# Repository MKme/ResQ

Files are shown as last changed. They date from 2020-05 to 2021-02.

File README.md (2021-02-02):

# RESQ Open Source Wifi based Search and Rescue Devices
Moving super secret source to Git for sharing on Hackaday- time to give ths project away  Show it some love with a like on Hackaday IO here: https://hackaday.io/project/172090-resq-search-and-rescue-tools

Buy a DIY kit here: https://store.mkme.org/?product_cat=custom

This open source project uses beacon packet sniffing from any commercially available aircraft/drone or manned aircraft OR by a handheld YAGI antenna unit to locate people on the ground such as lost hikers, 
campers or even poachers on game preserves etc This will work even in areas where their cellphones cannot connect to any cell tower- handy.  The aircraft dtects the AP beacon from their cellular phone, records the GPS coordinates for later ground use and transmits an alert to search teams on the ground
<p align="center">
<br>
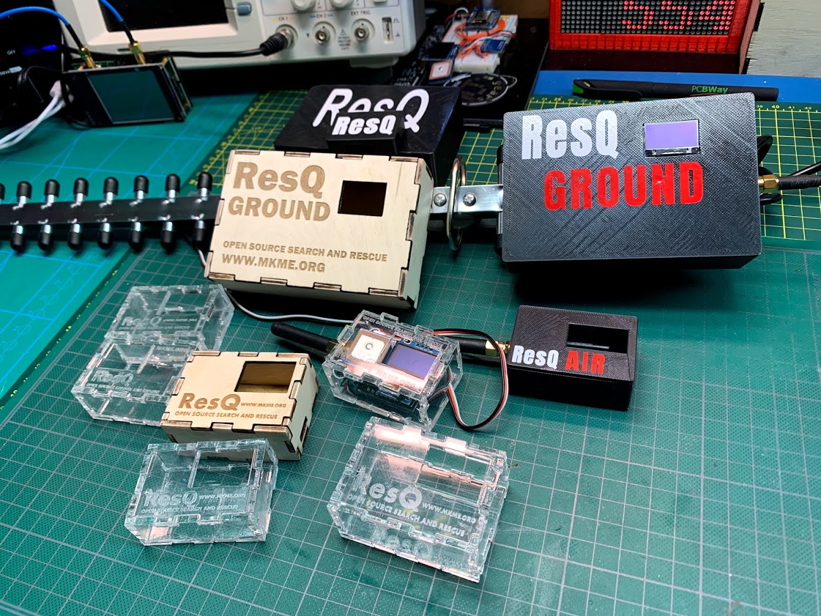
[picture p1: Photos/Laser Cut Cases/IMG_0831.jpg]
 
 <br>

<br>
<br>
🐦 <a href="https://twitter.com/mkmeorg">Twitter</a>
| 📺 <a href="https://www.youtube.com/mkmeorg">YouTube</a>
| 🌍 <a href="http://www.mkme.org">mkme.org</a><br>
Support this project and become a patron on <a href="http://mkme.org/patreon">Eric's Patreon</a>.<br>
Website, Forum and store are at http://mkme.org <br>
Chat with Me: <a href="https://discord.gg/j9S4Fgv">Discord</a></b>
</p>

# Links for more information
Hackaday Project: https://hackaday.io/project/172090-resq-open-source-search-and-rescue-tool

ResQ Tool Forum Thread For Discussion with Eric - http://mkme.org/forum/viewtopic.php?f=28&t=1130

# FULL video tutorials:

### Full playlist (all related videos/tutorials):

https://www.youtube.com/playlist?list=PLxyM2a_cfnzifVreG8aKurH-9nNYl8QLr

# Main Overview:
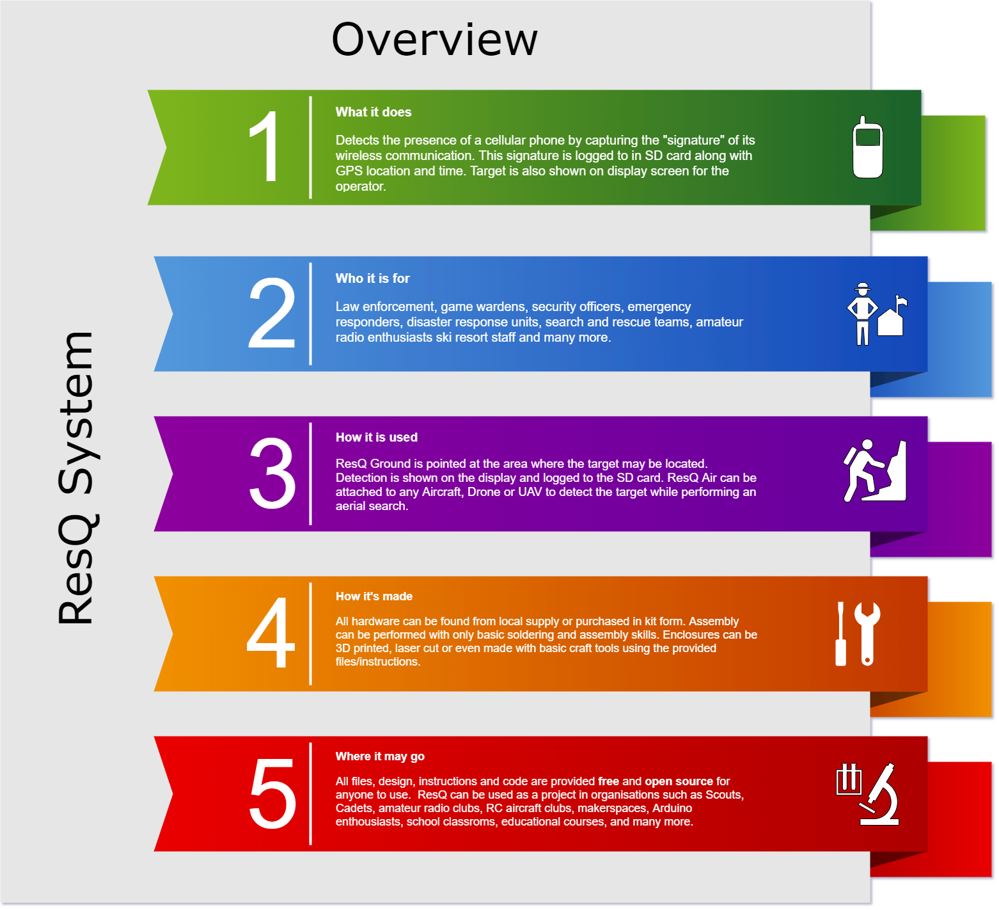
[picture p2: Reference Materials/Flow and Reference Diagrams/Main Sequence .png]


# System Overview 
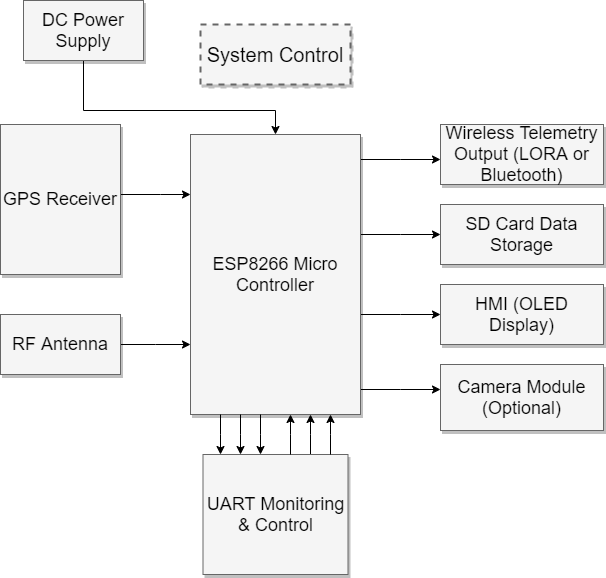
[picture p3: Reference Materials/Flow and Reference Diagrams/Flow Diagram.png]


# Kanban Board- Current Status of ResQ
 
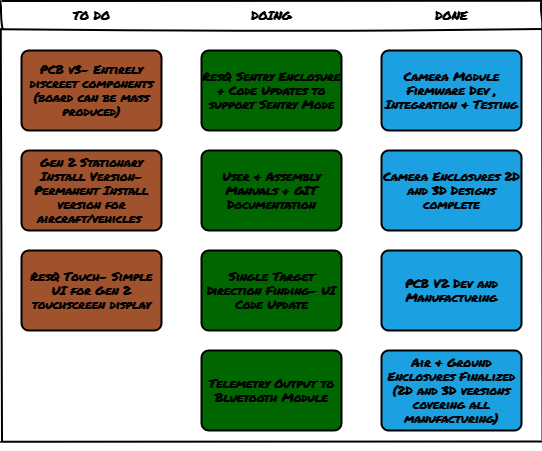
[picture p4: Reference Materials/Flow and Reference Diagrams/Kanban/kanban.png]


#  Bill of Materials 

This list is shortened for brevity - Full BOM in excel doc in BOM folder

| Component | Source  |
| --- |---|
|D1 Mini Pro | https://amzn.to/2ZQArbl
|Custom PCB |  https://store.mkme.org/?product_cat=custom
|D1 Mini With antenna included| https://amzn.to/2ZNQEy1
|SD Card Reader| https://amzn.to/2XPDv6B
|0.96" OLED Display| https://amzn.to/3cCHvvj
|2.4 GHz Yagi Antenna| https://amzn.to/3gwLso9
|BN220 GPS| https://amzn.to/2ZPXUJH
|SMA adapter| https://amzn.to/3ezOpT8
|LORA Modules| https://amzn.to/2zB61ze
|18650 LiOn cells | https://amzn.to/2ZSoMsz

# Wiring 
See schematic and PCB gerber files for detailed view but this is the summary
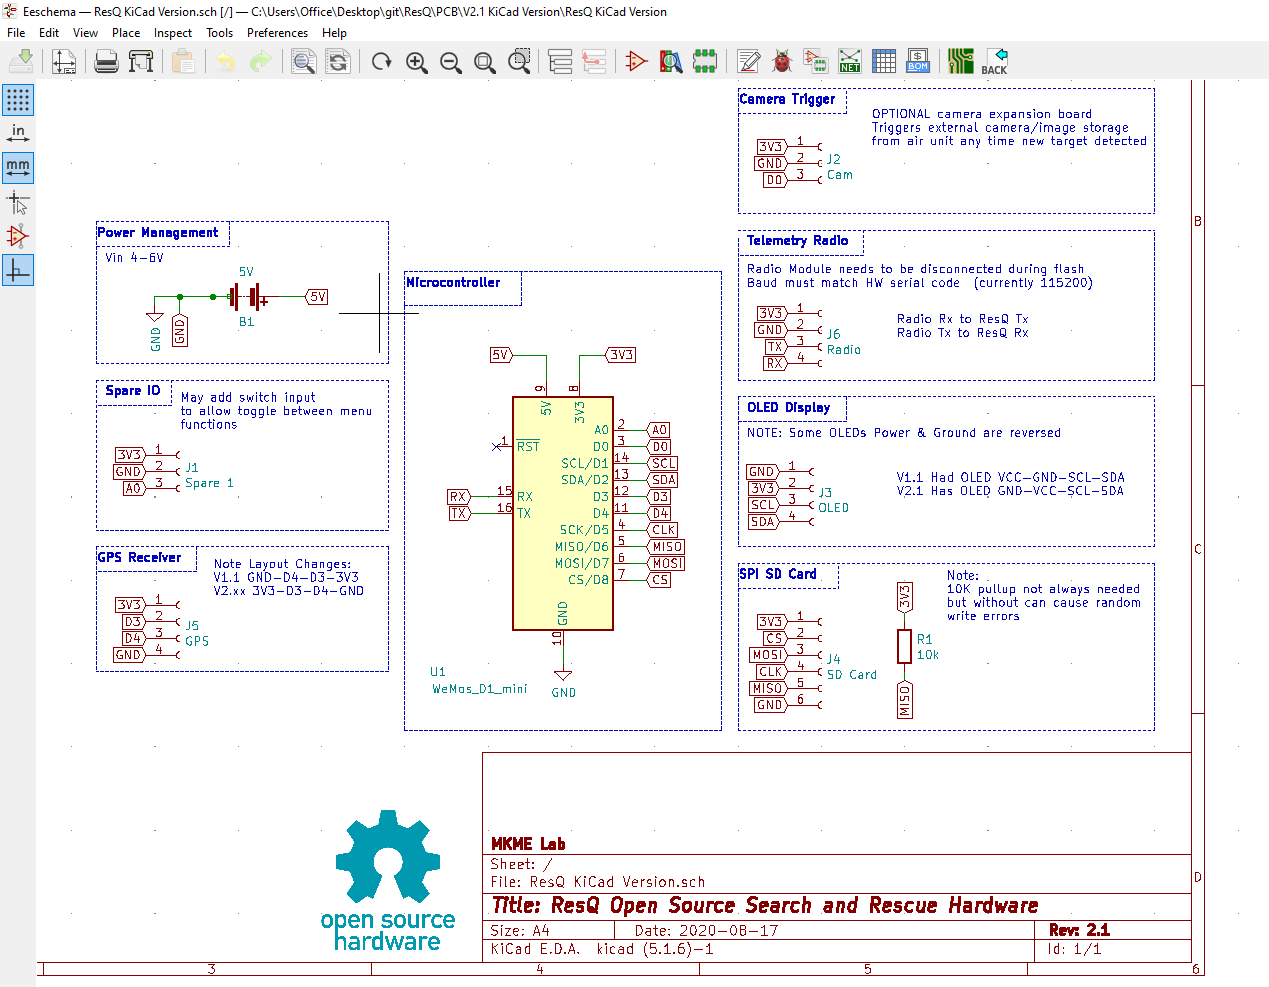
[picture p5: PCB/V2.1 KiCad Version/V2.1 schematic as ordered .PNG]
 

### SPI SD Card to WEMOS D1  Wiring
| Pin On SD Reader | Pin on D1  |
| --- |---|
| SCK  | D5 |
| MISO| D6 |
| MOSI  | D7 |
| CS  | D8  |
|GND | GND |
|VCC  | 3.3V ONLY!  |

### 0.96" OLED to WEMOS D1 
| Pin On OLED | Pin on D1  |
| --- |---|
| SDA  | D2 |
| SCL| D1 |
|GND | GND |
|VCC  | 3.3V or 5V (depends on display)  |

### BN220 GPS Module
| Pin On GPS | Pin on Wemos D1  |
| --- |---|
| TX | 4 (2 in Arduino code) |
| RX | 3 (0 in Arduino code) |
|GND | GND |
|VCC  | 3.3V |

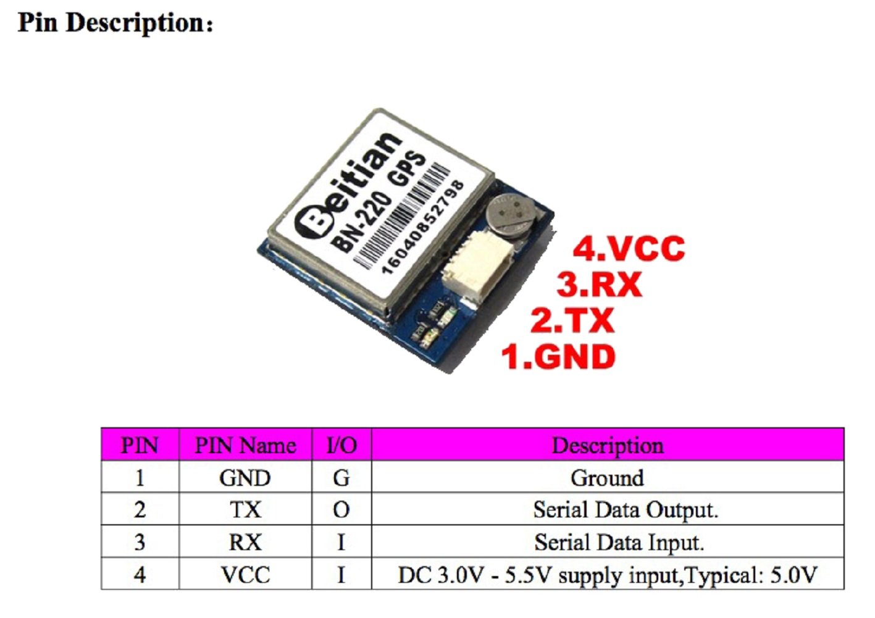
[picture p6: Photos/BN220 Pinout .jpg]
 

# Enclosure/CAD Files Notes
- V1.4 Air unit case is first compatible enclusure for V1.1 PCBs/Gerbers as manufactured/supplied
- All boards and enclusures will follow version 1.XX will be compatible with all 1.XX PCBs and onward to 2.xx etc
- This project is my first made with Fusion 360 
- This was made from the awesome Adafruit Tutorial here (Thanks Noe!) https://www.youtube.com/watch?v=VVmOtM60VWw
- The box is fully parametric in Fusion so you can easily modify it as your needs/expansion or future changes to this project- HANDY!

# PCB Notes
## V1.1 
First to be manufactured (PCBWay)
- OLED is powered by 5V not 3.3V (just note in case yours is not 5V tolerant)
- OLED Wiring startes with VCC on the end then GND- Apparently almost every other OLED in the world outside my shop starts with GND then VCC
- OLED can be wired backwards as above point and burn your fingers....twice.... but still works after.... sigh....

## V2.1 
Project files done in KiCAD
- OLED is now powered 3.3V not 5V
- OLED VCC and Grnd reversed to accomodate the much more common pin layout 
-Pullup resistor added for SPI line
- Spare Signal wires now routed and dont need bodge wires if used
- Serial lines broken out for teletry transmission via LORA radio (or other UART radio module)

# Camera Expansion Module

ResQ Camera expansion module automatically captures images when target is aquired. This uses an ESP32 with camera
module. With the single GPIO I use this as an interrupt driven signal to wake the ESP from deep-sleep then begin capturing images to the SD card

The images can be used to correlate with the satellite imagery or existing aircraft FPV DVR footage.  It may be handy to have standalone images to quikly review any target detected. 

The code and enclosure files are now posted to this repo for all to use. Refer to the assembly manual for details. 

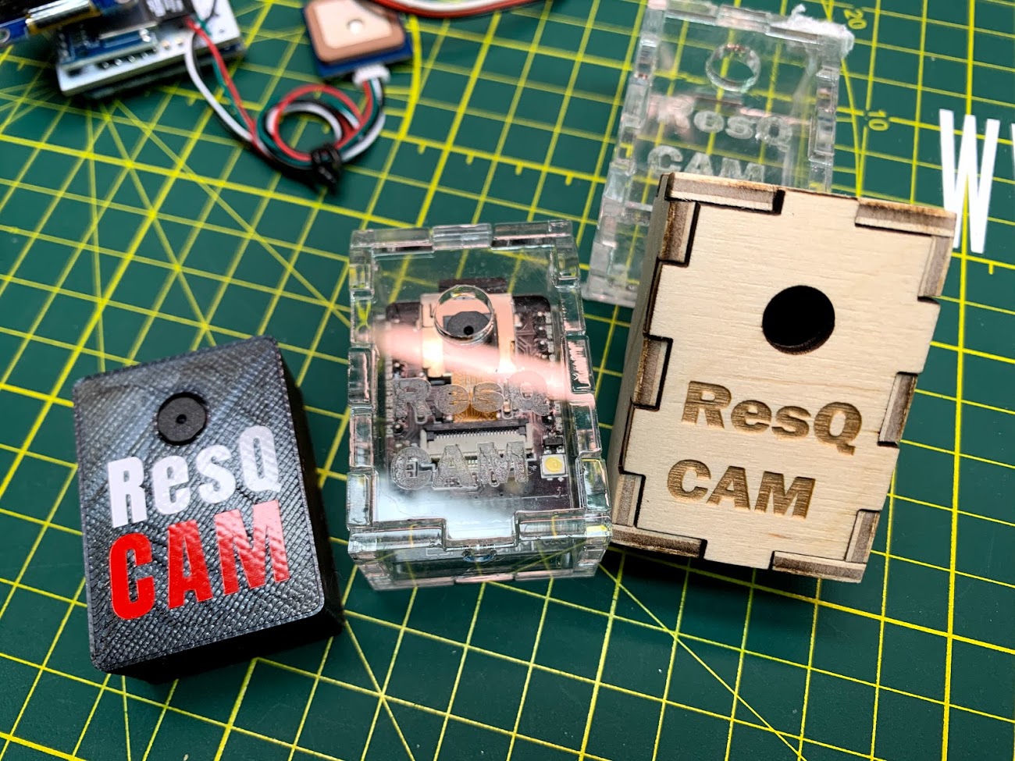
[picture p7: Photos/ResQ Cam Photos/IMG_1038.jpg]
 

# ResQ Sentry

Sentry is a ResQ variant which includes the existing hardware plus the camera module inside a case which then becomes a stationary camera for monitoring human traffic in any area. Any time a new cell phone MAC address is detected- the camera module is triggered and captures still images of the area. 

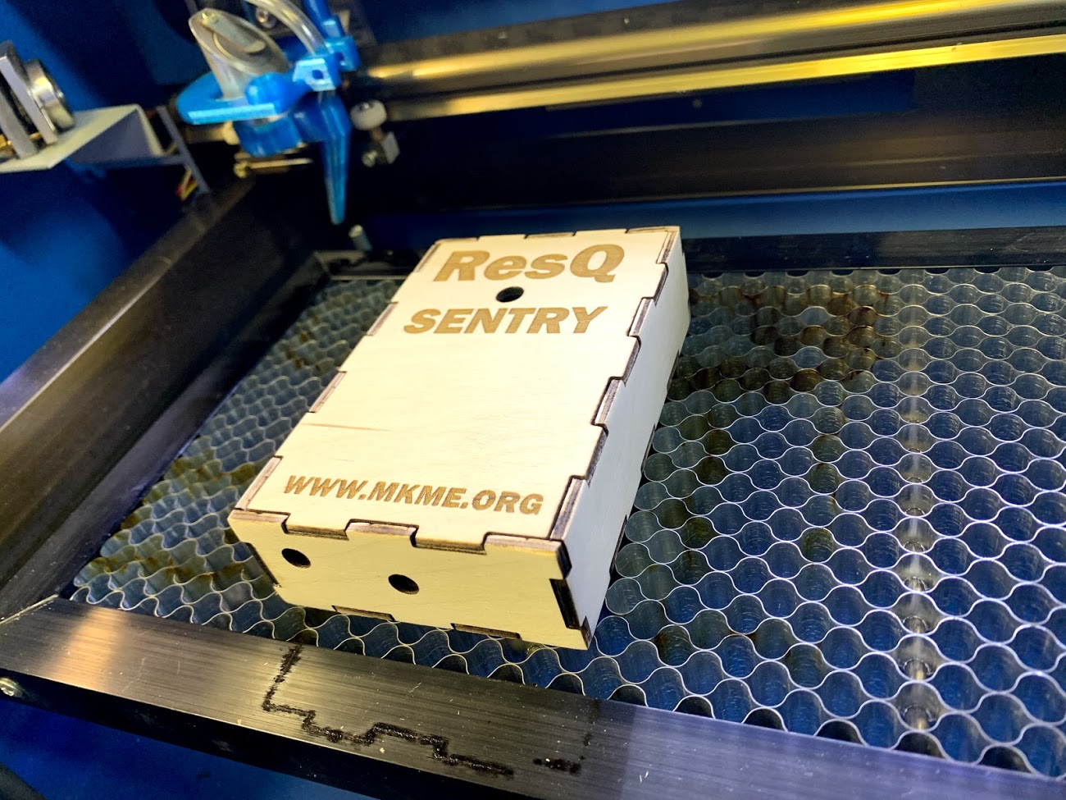
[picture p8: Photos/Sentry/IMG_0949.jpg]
 
 
This can be used in game preserves to catch poachers, private property surveillance, restricted areas, and many more! 

The GPS is still used to allow for accurate date/time stamps without the need for adding a real time clock. Time function will work without clear line of site to any satellites (it works indoors just fine).

2 different enclosures are provided:

- 	3D printable .stl version
-  Laser cut version (.svg files)

1. Install the ResQ hardware along with the camera in to the Sentry enclosure (camera through front hole)

2. Power the Sentry with an appropriate battery supply (5VDC to the ResQ) 

3. Add an appropriate solar charging system if desired (I bought this panel for $21 CAD) https://amzn.to/3hOA5qX

# Reviewing a Search Result Data Recording

All data is stored to the SD card while the unit is powered on. Perform your search then afterward- remove the SD card and download the contents to your PC. The file is datalog.txt 

You can manually review the hits and plot them one by one in Google Maps or your preffered map software or you can do them all at once: 

1. Download the datalog.txt file, 

2. Rename from datalog.txt to datalog.csv

3. Open in excel - Add a row above the data and within that row add the text LAT, LONG and MAC  above the corresponding columns for each (this will tell Google what each column is)

4. Delete all other columns as we wont need those

5. Upload to Google maps as done here https://www.youtube.com/watch?v=SLMzhOoA29M  NOTE: Google seems to limit the plots to 2000 entries so ensure your CSV file only has less than 2000 lines. 

Now You can then see all the MAC addresses plotted on a map- HANDY! 

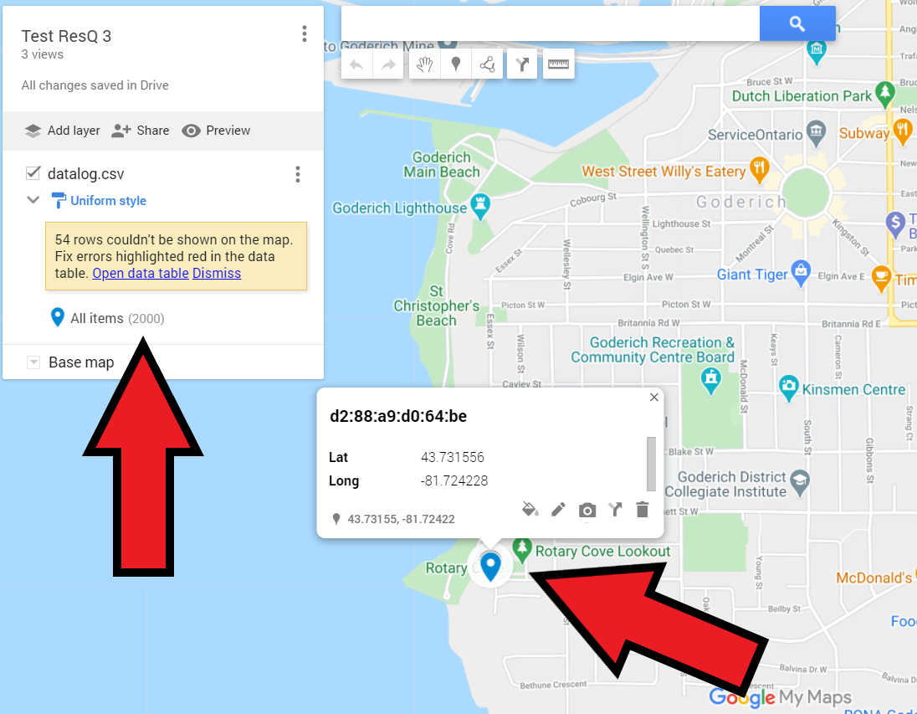
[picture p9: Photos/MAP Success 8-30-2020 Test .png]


# Reference & Press Coverage
Hackaday Article: https://hackaday.com/2020/08/12/resq-hunts-for-lost-hikers-from-the-air/

Hackaday Prize 2020 Finalist status: https://hackaday.io/contest/171491-supplyframe-designlab-2020-hackaday-prize/log/183401-2020-hackaday-prize-finalists

Hackster I.O Article: https://www.hackster.io/news/resq-aims-to-help-find-lost-hikers-by-capturing-wifi-beacon-frames-6608e10e4b22

Adafruit Article: https://blog.adafruit.com/2020/08/17/resq-hunts-for-lost-hikers-from-the-airdrone-droneday/

More videos and information at http://youtube.com/mkmeorg or http://www.mkme.org
Support this project and become a patron on <a href="http://mkme.org/patreon">Eric's Patreon</a>.<br>
Website, Forum and store are at http://mkme.org <br>
Chat with Me: <a href="https://discord.gg/j9S4Fgv">Discord</a></b>

### ResQ Components/build:

D1 mini Pro External Antenna (you need to mod the board for the external to work)  https://youtu.be/hXRcJXMjlyg

SD Card Use: https://youtu.be/y-P627KBLBw
SD Card interface: http://mkme.org/forum/viewtopic.php?f=14&t=1126&p=1430#p1430

### Drone/Aircraft Builds and Tuning:

Nano Talon Build Pt 1 https://youtu.be/BveRkukH6Sg

Nano Talon Build Pt 2 https://youtu.be/9segL9kFlmg

Nano Talon Build Pt 3 https://youtu.be/56KqzPDGRqc

Nano Talon Build Pt 4 https://youtu.be/-qZ3yurwyJo

Adding 3DR telemetry radio to the Nano Talon for autonymous flight control https://youtu.be/XCQz9AeE2qA

Making a DIY 18650 2S1P battery pack for >1hr duration flight missions https://youtu.be/XwAqgR_XsYw

### Attribution

This work is licensed under a Creative Commons Attribution-NonCommercial 4.0 International License.
https://creativecommons.org/licenses/by-nc/4.0/
See notes.h and comments in main code for detailed lineage/license info

Credit M. Ray Burnette for publication as WiFi Sniffer 20161013 (MIT) 
Source https://www.hackster.io/rayburne/esp8266-mini-sniff-f6b93a  
Ray's example helped this whole project by providing a base to work and expand from.  Ray your code caused me to pull my hair out and jump for joy many many nights. You rock. I apologise for the current mess that once resembled some of your code :) 

Credit to Andreas Spiess for inspiring all of us to use ESP8266 boards more in our projects (Andreas=father of all ESP projects) : https://www.youtube.com/channel/UCu7_D0o48KbfhpEohoP7YSQ

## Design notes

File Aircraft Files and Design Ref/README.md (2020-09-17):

# Aircraft Ref

### Welcome to Erics land of ResQ Aircraft Reference Materials
This area is for my aircraft goodies and drone configs.  

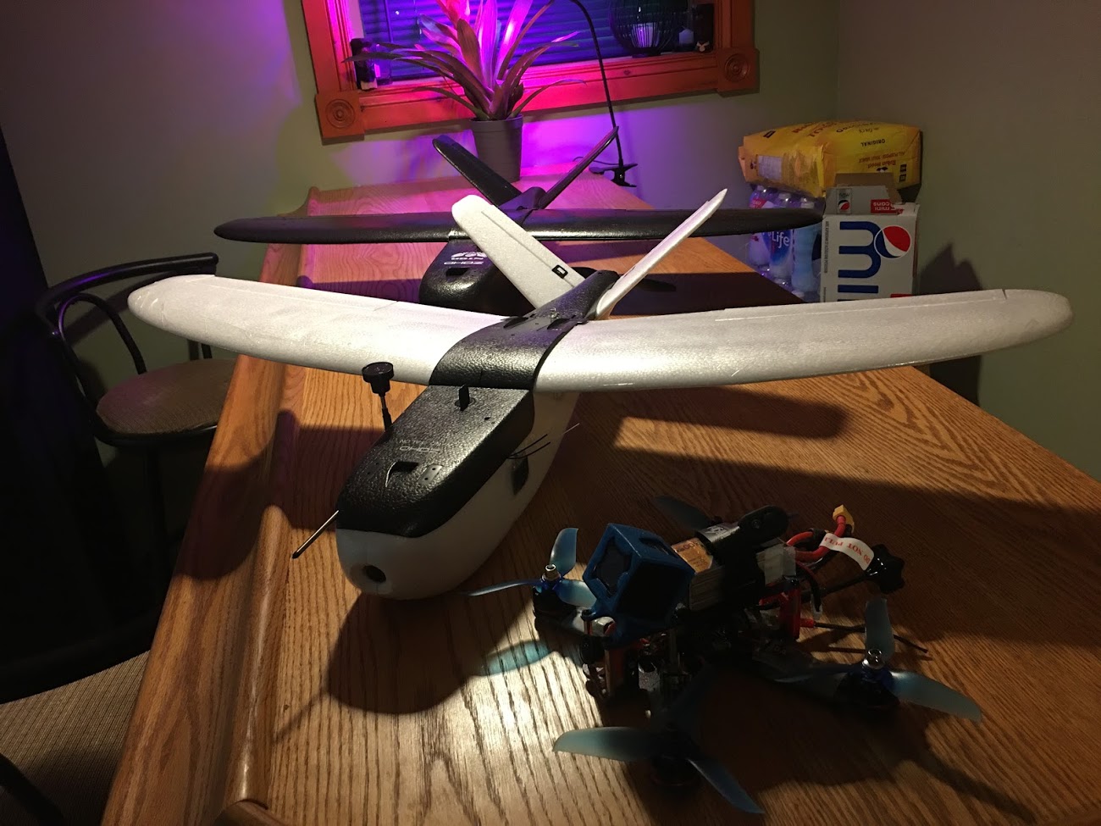
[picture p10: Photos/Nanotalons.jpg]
 

# Aircraft Notes 

4-1-2020:

- iNav fully updated and old settings manually inputted. 433mhz telemetry working for wireless/mission

July 2020:

- inav fully tested- just needs final autotune or pid adjustments

- trim good

- all modes working

- transition to RTH is still rough and too high throttle- would be nice to reduce this but seems to rely on rate or some combination

See my YouTube videos in the ResQ playlist https://www.youtube.com/playlist?list=PLxyM2a_cfnzifVreG8aKurH-9nNYl8QLr

Also see my entire Github repo devoted to my drone configs (ALL OF THEM) here:  https://github.com/MKme/DroneConfigs

See the CAD files folder for my 3D printed parts

In the iNav folder you will find all my iNav config files for the Nano Talon. You should be able to use them directly in your build should you use the same airframe.  

More configs coming Fall 2020 when I build the new heavy-lift quadcopter. 

## TIPS- 

-  I have the aircraft and quacopter parts avaialble on my website here: http://store.mkme.org

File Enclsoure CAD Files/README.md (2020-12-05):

# Enclosures Assembly & Manufacturing Guide

### Welcome to Erics land of enclosures where everyone leaves with a shiny new project case. No matter what tools you have we have a case for you. No money down, no interest for all the days! 

 

Here we have a variety of selections for your ResQ build.  Choose from the standard CAD files and .stls for 3D printing

### or

Try out the new and improved 2D svg files to laser, CNC or even hand cut your own!  No special equipment needed anymore. My goal was to make sure no one would be limited by their access to machinery or equipment- below are options for multiple enclosures depending on what you have access to or even nothing at all!

## 3D Printer Settings

Print in your material of choice. I use PLA:

- 0.3mm Layer height

- 210C extruder

- No Supports

- 15% Infill Rectillinear

You find ALL my i3 printer settings in GIT here:  https://github.com/MKme/I3-Mega-3D-Printer-Settings-Resources

Or All my CR10 settings and profiles in GIT here:  https://github.com/MKme/CR10-3D-Printer-Settings-and-Reference

## Laser Cutter Settings
On my K40 (40 Watt Chinese laser cutter) You can find all my reference and info for the K40 in my Git Repo Here: https://github.com/MKme/Laser-Cutter

Settings Used for these designs: 

### Acrylic

- Raster: 10% power 100mm/second

- Vector Cuts: 60% power 3mm/s 

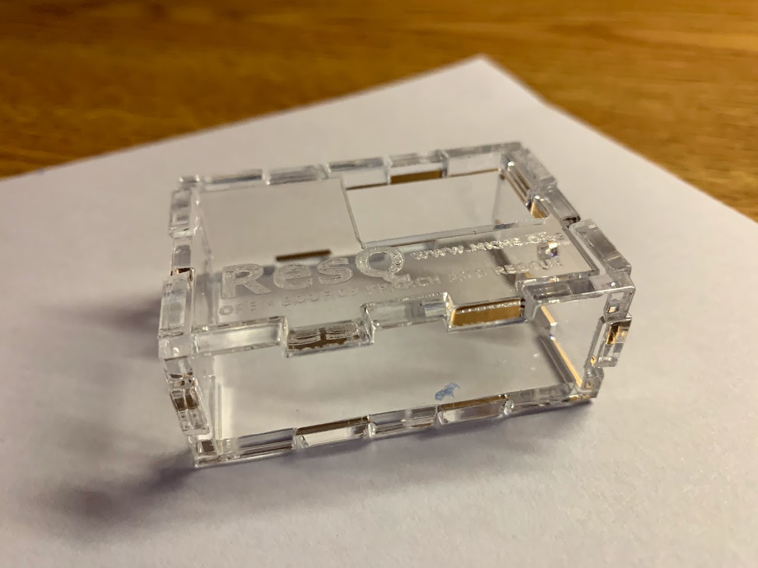
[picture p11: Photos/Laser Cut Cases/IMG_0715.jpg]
 

### 3mm Birch Plywood

- Raster: 11% power 100mm/second

- Vector Cuts: 60% power 3mm/s 

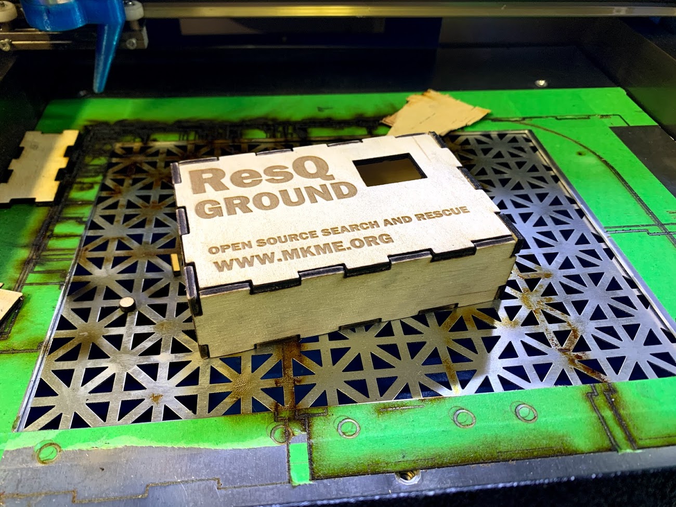
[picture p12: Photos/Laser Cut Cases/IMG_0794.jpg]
 

## CNC
I dont have one yet but if you have tips please let me know so I can add them to the assembly guide and this doc!

*EDIT* I bough a 3018 CNC to test these 2D files and see how they cut compared to the laser. If there is anything I can do to fix them for others to easily make them I will. 

## Hand cutting

Print out the design on paper then trace it on your material of choice and cut it out.  

Just that easy! 

### TIPS- 

- Hand made verision : Use DollarTree foam board then just wrap it in packing tape for a super durable enclosure that costs you a dollar.  

- Modify the Box files yourself- If you want different dimensions simply go to this site: https://en.makercase.com/#/ Enter the dimensions you want and export the .svg for FREE

## Enclosure/CAD Files Notes

V1.4 Air unit case is first compatible enclusure for V1.1 PCBs/Gerbers as manufactured/supplied

All boards and enclusures will follow version 1.XX will be compatible with all 1.XX PCBs and onward to 2.xx etc

This project is my first made with Fusion 360

Fusion 360 models were made from the awesome Adafruit Tutorial here (Thanks Noe!) https://www.youtube.com/watch?v=VVmOtM60VWw

The fusion 360 boxes are fully parametric in Fusion so you can easily modify it as your needs/expansion or future changes to this project- HANDY!

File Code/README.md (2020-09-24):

# Code Guide

### Welcome to Erics land of ResQ Arduino Code
This is where you will find the current code/firmware for the ResQ project 

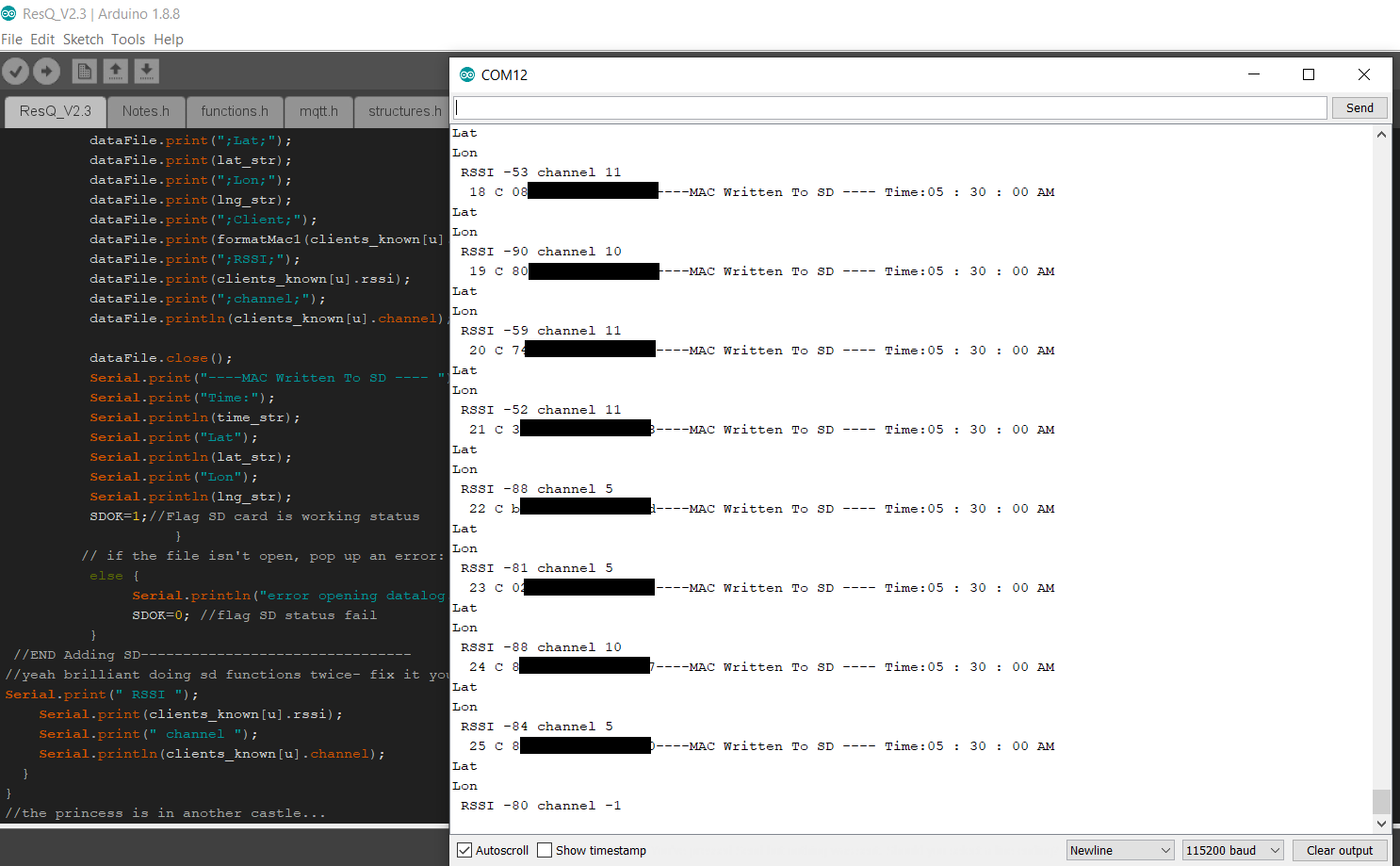
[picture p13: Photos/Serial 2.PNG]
 

# Code Notes

To program the ESP8266 you need to install the Arduino IDE, ESP8266 board support within the IDE and the CH340 USB to Serial driver (if not already installed on your PC)
To do this follow the tutorial here:  

https://www.youtube.com/watch?v=q2k3CzT5qE0&ab_channel=MakersMadLab

NOTE: ResQ kits come with the ESP8266 programmed with the current ResQ firmware at the time of manufacture. 

Install the supporting libraries called out in the sketch (they are also included as backups in the GitHub Repo for you as libraries can be broken by new development.  Needed libraries are: 

•	ArduinoJson

•	TinyGPSPlus-1.0.2/TinyGPSPlus-1.0.2

•	U8g2-2.27.6

•	EspSoftwareSerial-6.8.1.zip

For help installing libraries see this video: 

https://www.youtube.com/watch?v=M6PZOqNHKxM&ab_channel=Brainy-Bits

Flash the most current ResQ firmware (sketch) found on GitHub here: https://github.com/MKme/ResQ/tree/master/Code

## Options 

Sentry Mode can be enabled in setup by changing:

int SENTRYMODE = 0;

to

int SENTRYMODE = 1;

This will turn off the OLED after unit is fully initialized and detects the first target thereby saving battery power for solar/battery installs

## TIPS- 

-  I have the PCBs avaialble on my website here: http://store.mkme.org/product-category/custom/
-  Backups of the working libraries are found in this directory

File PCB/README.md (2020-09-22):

# PCB and Schematics Guide 

### Welcome to Erics land of Printed Circuit Boards where everyone leaves with a shiny new project board or schematic! 

 

Here we have a variety of selections for your ResQ build.  

# PCB History

## V1.1 
First to be manufactured (PCBWay)
- OLED is powered by 5V not 3.3V (just note in case yours is not 5V tolerant)
- OLED Wiring startes with VCC on the end then GND- Apparently almost every other OLED in the world outside my shop starts with GND then VCC
- OLED can be wired backwards as above point and burn your fingers....twice.... but still works after.... sigh....
- Extra unused I/O is broken out (you have to add jumper wires for signal if you want to add anything) but not routed- they are fully functional in V2 and beyond
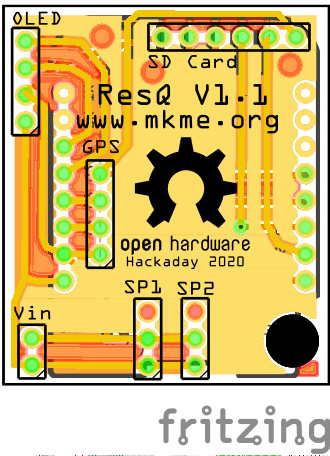
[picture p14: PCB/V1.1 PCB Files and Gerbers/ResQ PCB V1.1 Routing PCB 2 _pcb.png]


## V2.1 
Project files done in KiCAD and provided here for you!
- OLED is now powered 3.3V not 5V
- OLED VCC and Grnd reversed to accomodate the much more common pin layout 
- Pullup resistor added for SPI line
- Spare Signal wires now routed and dont need bodge wires if used
- Support for external camera expansion module added
- Serial lines broken out for teletry transmission via LORA radio (or other UART radio module)
- Ordered from PCBWay Sept 6th 2020 
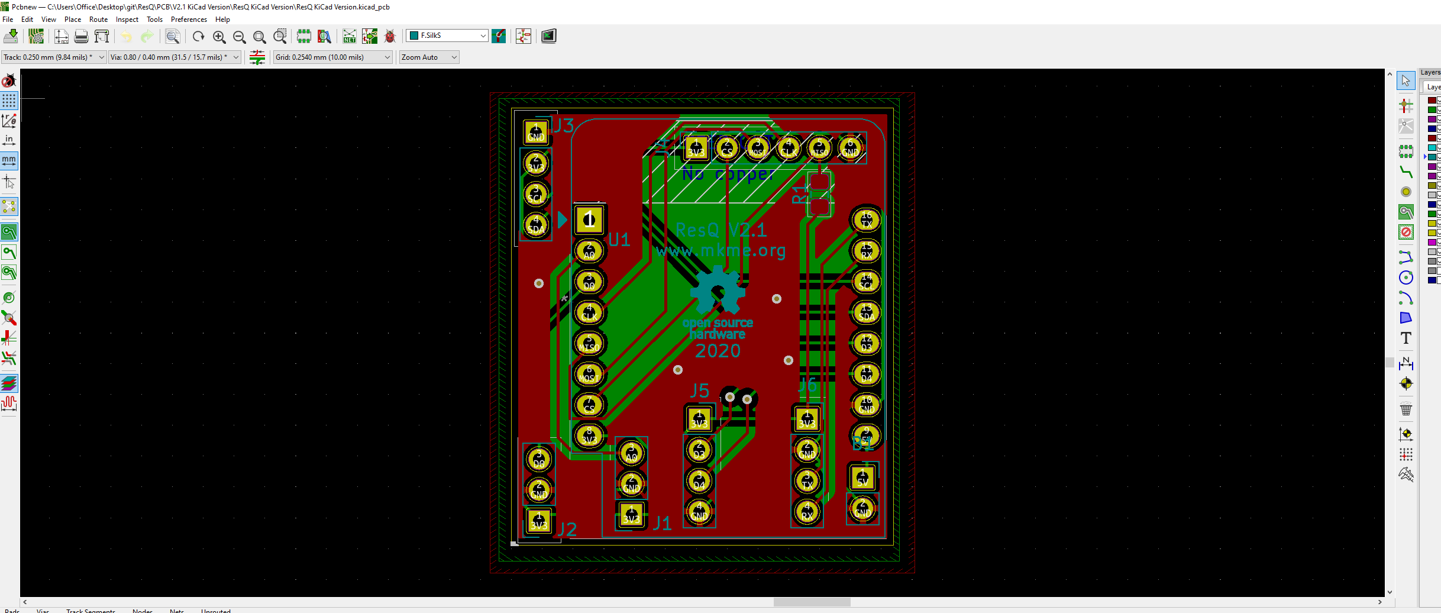
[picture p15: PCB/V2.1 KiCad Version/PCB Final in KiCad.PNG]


## V2.2

- Nothing yet and hopefully don't need it :)

## TIPS- 

-  I have the PCBs avaialble on my website here: http://store.mkme.org/product-category/custom/
-  You can also make your own PCB under $10 at PCBWay, JLCPCB, OSHPark or other board house of your choice!  Just upload the Gerbers I have provided here and you are all set!

## Notes and Handy Informationz

V1.4 Air unit case is first compatible enclusure for V1.1 PCBs/Gerbers as manufactured/supplied

All boards and enclusures will follow version 1.XX will be compatible with all 1.XX PCBs and onward to 2.xx etc

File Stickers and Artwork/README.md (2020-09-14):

# Stickers

### Welcome to Erics land of ResQ stickers and other artwork
Print these and cut on your cutter of choice (I use a Cricut)

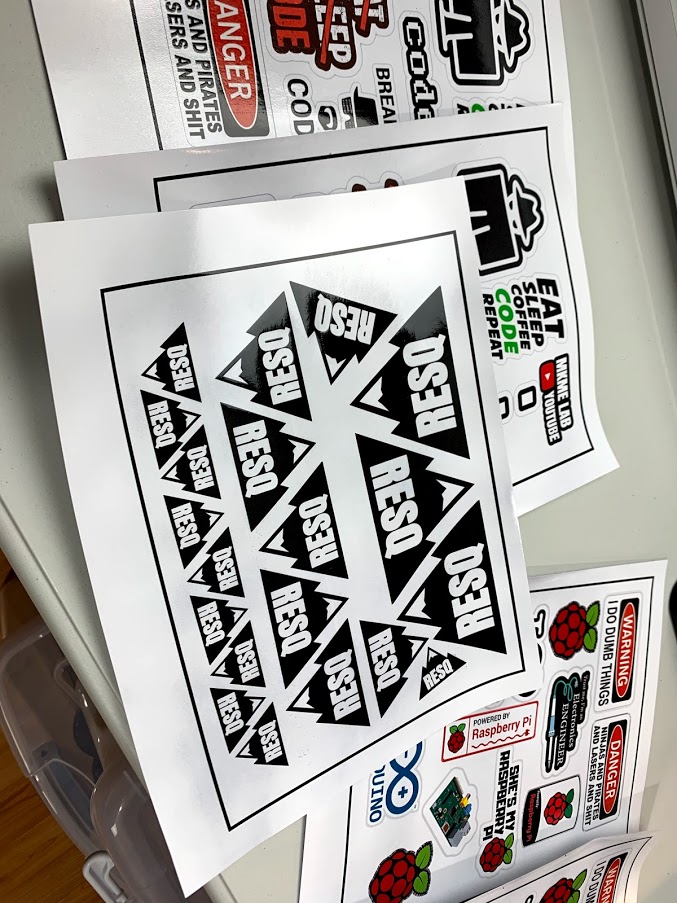
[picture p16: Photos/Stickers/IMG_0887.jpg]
 

# Stickers notes

See my YouTube videos in the ResQ playlist https://www.youtube.com/playlist?list=PLxyM2a_cfnzifVreG8aKurH-9nNYl8QLr

## TIPS- 

-  I have made stickers kits and various parts avaialble on my website here: http://store.mkme.org/product-category/custom/

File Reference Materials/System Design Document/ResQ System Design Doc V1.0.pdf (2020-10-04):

### RESQ

WWW.MKME.ORG
OPEN SOURCE SEARCH AND RESCUE

### SYSTEM DESIGN DOCUMENT

V1.0

Overview

This open source project investigates using AP beacon packet sniffing to locate people such as lost hikers, campers and even poachers in game preserves. This works anywhere- as long as wifi is enabled on the targets phone. The hardware detects the beacon frames from their cellular phone, records the GPS coordinates for use later.

2 are made:

- Hand-held portable
- Airborne carried by plane or drone

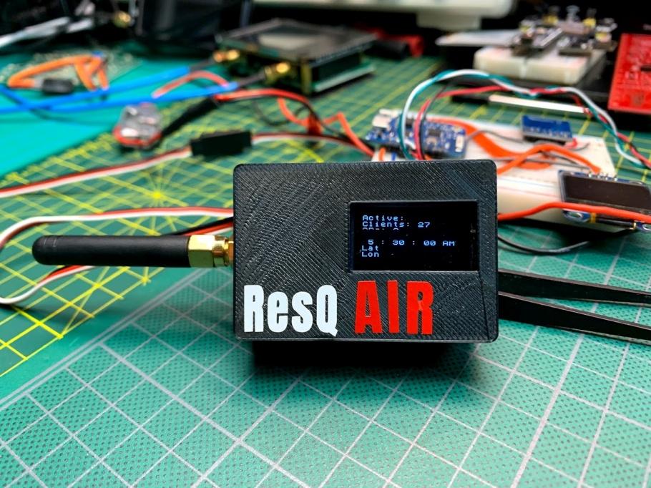
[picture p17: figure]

OPEN SOURCE SEARCH AND RESCUE

Revision Sheet

Release No. | Date | Revision Description
Rev. 0 | 06/01/2020 | Initial design doc

### 1 INTRODUCTION

### 1.1 Purpose and Scope

This document is a work in progress and will be updated OFTEN.

# Thanks for your understanding!

The ResQ tools will be able to deploy anywhere in the world cheaply and not dependant on any external support system. They can be made locally and deployed to search and rescue personnel, game wardens, law enforcement and many more.

### 1.2 Project Executive Summary

I [Eric] was inspired by the constant stream of search and rescue operations on the television show "North Woods Law". Each week they struggled to find lost people in the remote/rugged areas of Maine U.S.A. These areas often have no cellular service but in almost every case the target people had cellular phones on them and working. As I live in Canada- we have a surplus of these situations in our vast wilderness as well. I theorized I could use an external 2.4GHz antenna to receive the beacon frames from those phones ad capture that data.

This project tested that theory and proved that simple hardware could be used to detect the presence of a cellular phone in areas of limited visibility or access.

### 1.2.1 System Overview

This hardware can be embedded in to any very small drone or RC aircraft. It can also be attached to existing manned aircraft already participating in the search.

Using small drone aircraft (like the Nano Talon I use here) gives all the advantages such

OPEN SOURCE SEARCH AND RESCUE as flight condition tolerance, height, terrain, time of day etc that drones have over manned aircraft. They can also be sent on the full way-point mission without human intervention and tracked live from any ground station.

What it does (both air unit and ground unit):

- Detects all Beacons and their mac addresses within range
- Detects All AP's in range (not needed but why not log them anyhow)
- Gets GPS Lat/Long positioning
- Gets GPS UTC Time
- Logs all the above to the SD card .csv file every time any device detected changes
- Displays the number of clients detected, APs detected, time and Lat/Long on the OLED screen live.

Air unit will eventually send telemetry to ground control for live alerts (likely using existing 433MHz telemetry already sending flight data or LORA radio link)

Flow:


OPEN SOURCE SEARCH AND RESCUE

Build:

I started this build in 2018 and have proven out the Nano Talon airrframe to be a very worthy commercial candidate with good payload and HUGE flight times while operating fully autonomously. The Nano Talon breaks down small for easy transport/storage.

So far I am using the Wedmos D1 mini PRO with an external antenna (YAGI or Rubber duck) to receive the beacon frames, log them to SD Card with RSSI values (adds more precise direction finding if you fly a grid pattern) to review the MAC address list as well as plot with Google Earth/maps. I can easily transmit this via LORA or NRF module to the ground instantly as well. This will be logged as a separate version of the hardware.

Video:

https://youtu.be/FxJkW-vr78s

### 1.2.2 Design Constraints

Space in/on any aircraft or drone is limited so care had to be taken to keep the size and weight of the air unit to a minimum. Current design can be drastically reduced further with a small PCB redesign (put all components on ONE board)

Handheld ground unit supply is limited to conserve weight but can easily be expanded if the situation requires. LiPo batteries can also be substituted for LiOn units to increase capacity by weight.

### 1.2.3 Future Contingencies

PCB redesign to place ESP8266, SD slot and OLED on single board with charge control circuit.

Amplification circuit with LNA can be added to increase target detection (not currently needed)

LORA/Wireless telemetry downlink from Air unit under final development

Camera trigger- Yes we can even trigger an external camera! Coming soon…

### 1.3 Document Organization

References/links will be provided throughout to external sources when applicable. Source files in GitHub repository will contain the most up to date information as it will accept community submissions as this project evolves.

OPEN SOURCE SEARCH AND RESCUE

### 1.4 Points of Contact

Support provided via the forum at http://mkme.org/forum as well as the GIT repository. https:// https://github.com/MKme/ResQ

Support for the libraries used to support the code is provided by the original authors only. Restrictions for use can be found on their respective support pages (linked within the Arduino Source Code and reference materials

Forum Thread:
http://mkme.org/forum/viewtopic.php?f=28&p=1435#p1435

### 1.5 Project References

Initial design completed fall 2018. Testing and updates ongoing via Hackaday website:

https://hackaday.io/project/172090-resq-search-and-rescue-tools

### 1.6 Glossary

Arduino- Arduino is an open-source computer hardware and software company, project and user community that designs and manufactures microcontroller-based kits for building digital devices and interactive objects that can sense and control the physical world.

The project is based on a family of microcontroller board designs manufactured primarily by SmartProjects in Italy, and also by several other vendors, using various 8-bit Atmel AVR microcontrollers or 32-bit Atmel ARM processors. These systems provide sets of digital and analog I/O pins that can be interfaced to various expansion boards ("shields") and other circuits. The boards feature serial communications interfaces, including USB on some models, for loading programs from personal computers. For programming the microcontrollers, the Arduino platform provides an integrated development environment (IDE) based on the Processing project, which includes support for C,C++ and Java programming languages.

I2C
WIFI
GPS
Software Serial
YAGI
Dipole
SPI
SD

### 2 SYSTEM ARCHITECTURE

Arduino C++ code running on Expressif ESP8266 provides basic operating system uploaded via Arduino IDE

OPEN SOURCE SEARCH AND RESCUE

### 2.1 System Hardware Architecture

1. Power Supply- USB powered or ANY 3-6VDC source
2. Wemos D1 Mini Pro ESP8266
3. 0.96” OLED
4. SD Card
5. GPS Receiver
6. Antenna (dipole air unit, yagi ground unit)
7. VCC/Power (air unit)
8. Battery Power (ground unit)
9. Enclosures

BOM maintained in GitHub Repository here: https://github.com/MKme/ResQ/tree/master/BOM

### 2.2 System Software Architecture

- Arduino Sketch (C++) operating on ESP8266 hardware
- Code Releases: https://github.com/MKme/ResQ/releases
- Source Code: https://github.com/MKme/ResQ/tree/master/Code
- Full code walkthrough: TBD

### 2.3 Internal Communications Architecture

- I2C bus from ESP8266 to OLED display for HMI
- Serial data UART RX/TX at 115200 baud rate for debugging/development
- Software Serial data at 9600 baud UART RX/TX for GPS receiver communication
- SPI Interface to micro-SD card (storage)

### 3 FILE AND DATABASE DESIGN

All files and updates via GitHub: https://github.com/MKme/ResQ

This work is licensed under a Creative Commons Attribution-NonCommercial 4.0 International License. https://creativecommons.org/licenses/by-nc/4.0/

### 3.1 Database Management System Files

- Datalog.txt on Secure Digital storage conatins all MAC addresses detected along with their GPS position and time detected in a comma separated values file (.csv)

OPEN SOURCE SEARCH AND RESCUE

### 3.2 Non-Database Management System Files

- Main code file and supporting header files. All can be found in the releases area on GitHub.

### 4 HUMAN-MACHINE INTERFACE

1. 0.96” OLED Display communicating via I2C datalines

### 4.1 Inputs

- Wireless 2.4Ghz Packet traffic captured/parsed by ESP8266 radio
- Datasheet:

### 4.2 Outputs

- Targets/Data displayed on HMI screen
- SPI Interface to Secured Digital Storage (SD card)

### 5 DETAILED DESIGN

### 5.1 Hardware Detailed Design

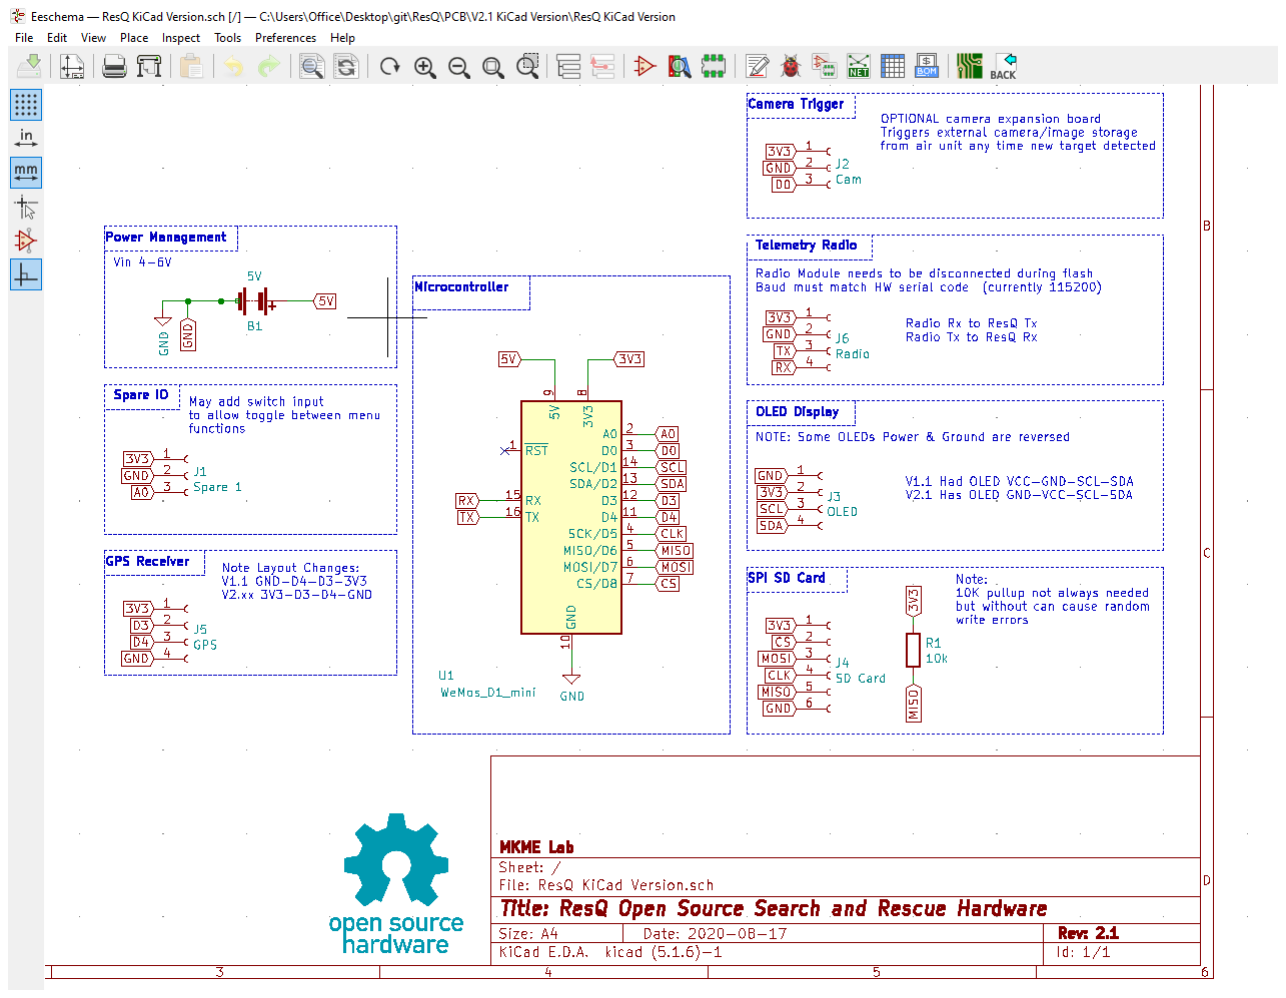
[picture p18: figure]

Schematic Diagram

OPEN SOURCE SEARCH AND RESCUE

### 5.2 Software Detailed Design

- Setup
- Loop

### 5.3 Internal Communications Detailed Design

- 115200 baud UART Hardware Serial
- 9600 baud UART Software Serial (GPS communication)
- I2C bus for HMI (display)
- SPI bus for SD Card Storage interface

### 6 EXTERNAL INTERFACES

- Camera trigger (Digital I/O pin)
- Telemetry radio via 115200 baud UART shared with programming USB

### 6.1 Interface Architecture

- 2 terminal UART for telemetry on PCB
- 3 terminal camera trigger interface (VCC,GND,Trig)

### 6.2 Interface Detailed Design

- 128X128 pixel OLED

### 7 SYSTEM INTEGRITY CONTROLS

- Internal hardware/software watchdog native to ESP8266 is active and will initiate reboot of the processor in the event of a code execution stoppage.
- No checksums or manifest otherwise in place
- Automatic recovery is initiated from any SD file issue (removal) whereby a new file is automatically created if not present on every power cycle
- If datalog.txt is present on the SD card at power up the file is not removed- new data is added in sequence.

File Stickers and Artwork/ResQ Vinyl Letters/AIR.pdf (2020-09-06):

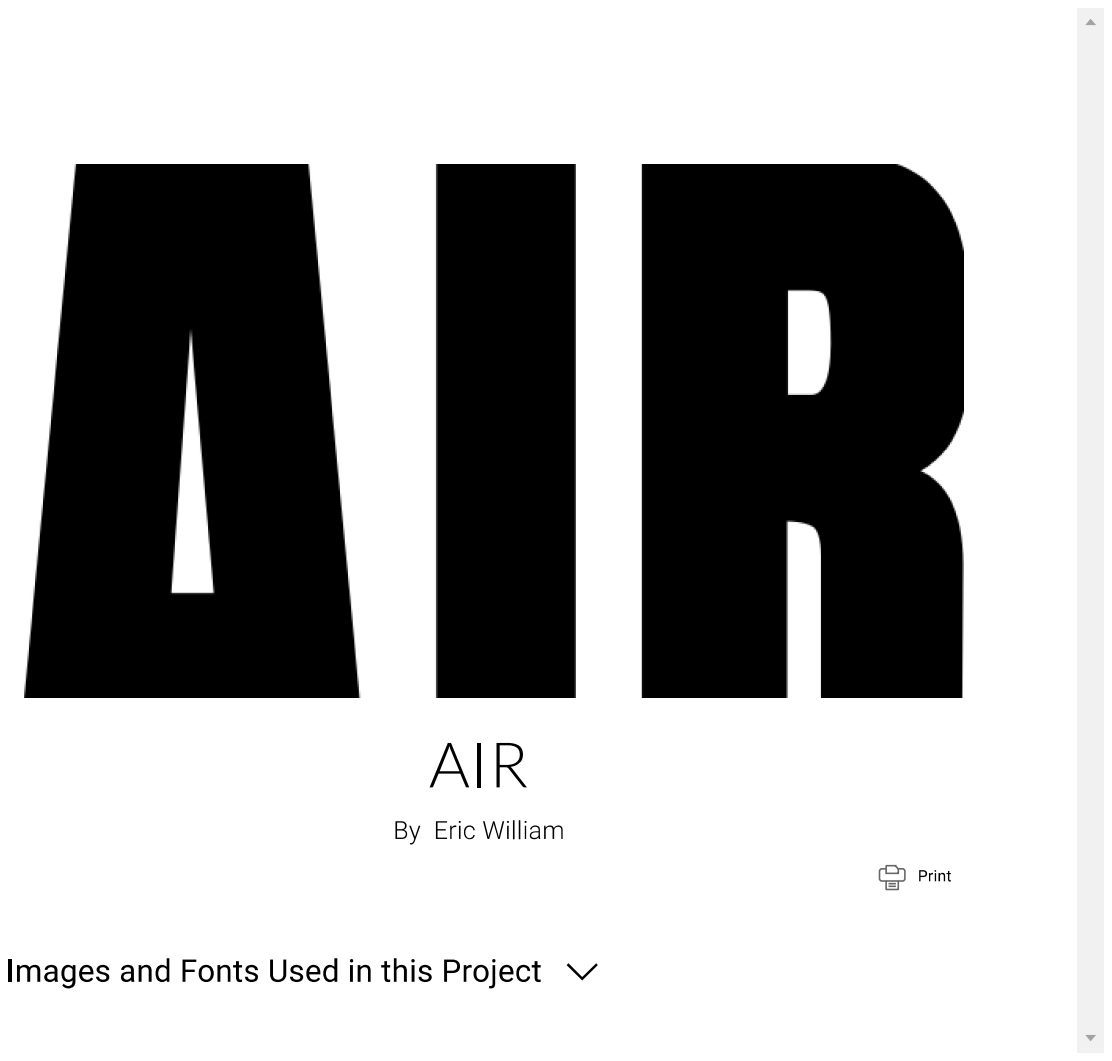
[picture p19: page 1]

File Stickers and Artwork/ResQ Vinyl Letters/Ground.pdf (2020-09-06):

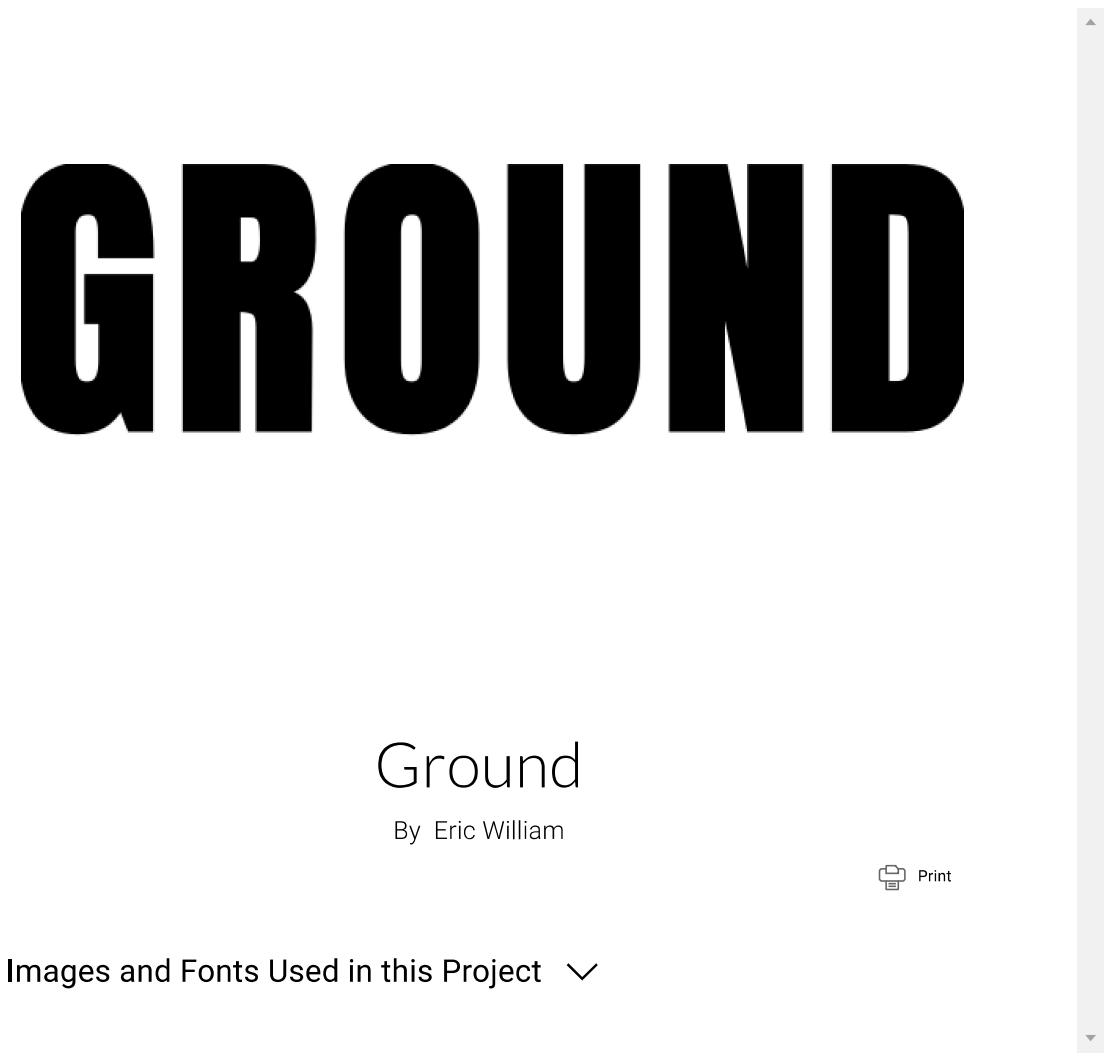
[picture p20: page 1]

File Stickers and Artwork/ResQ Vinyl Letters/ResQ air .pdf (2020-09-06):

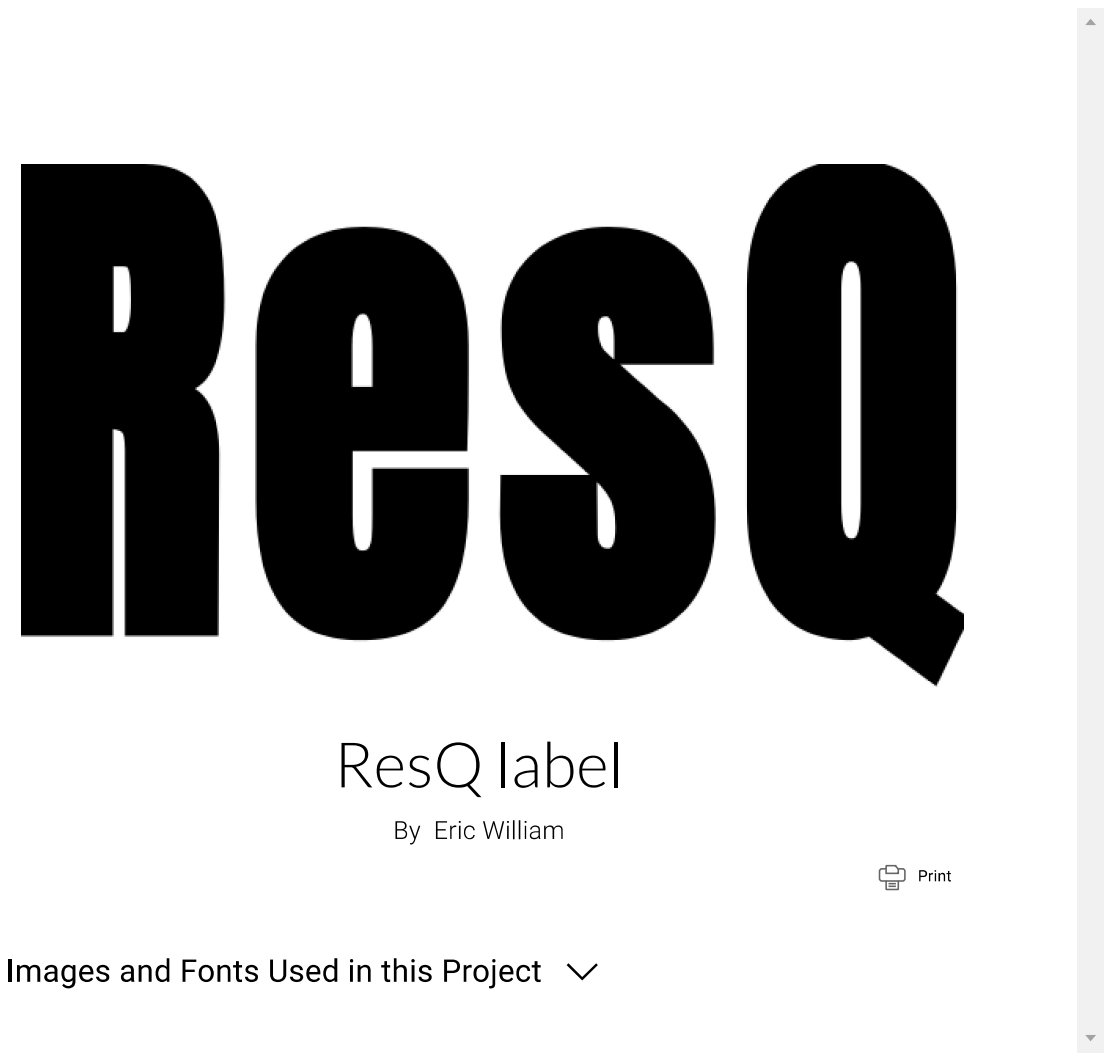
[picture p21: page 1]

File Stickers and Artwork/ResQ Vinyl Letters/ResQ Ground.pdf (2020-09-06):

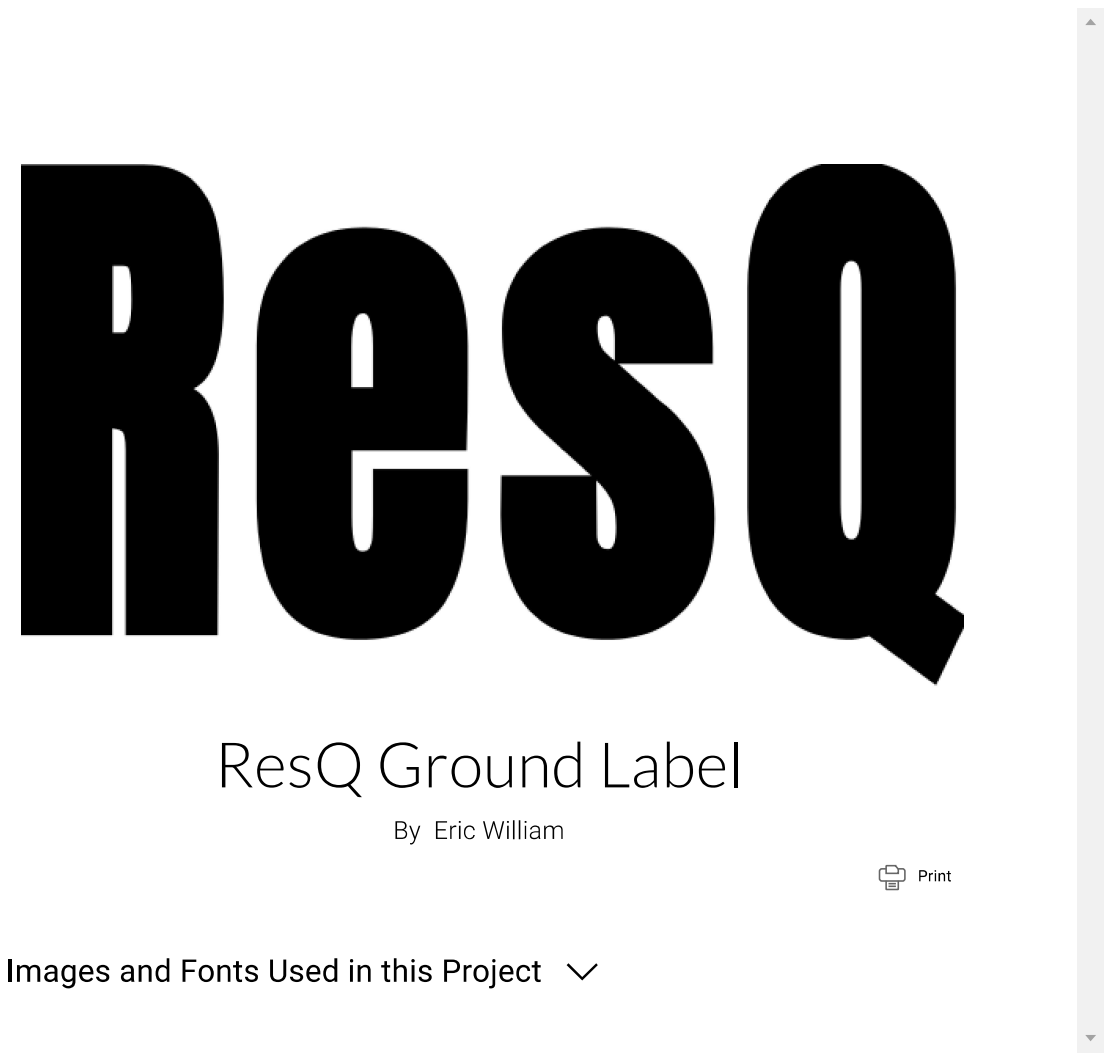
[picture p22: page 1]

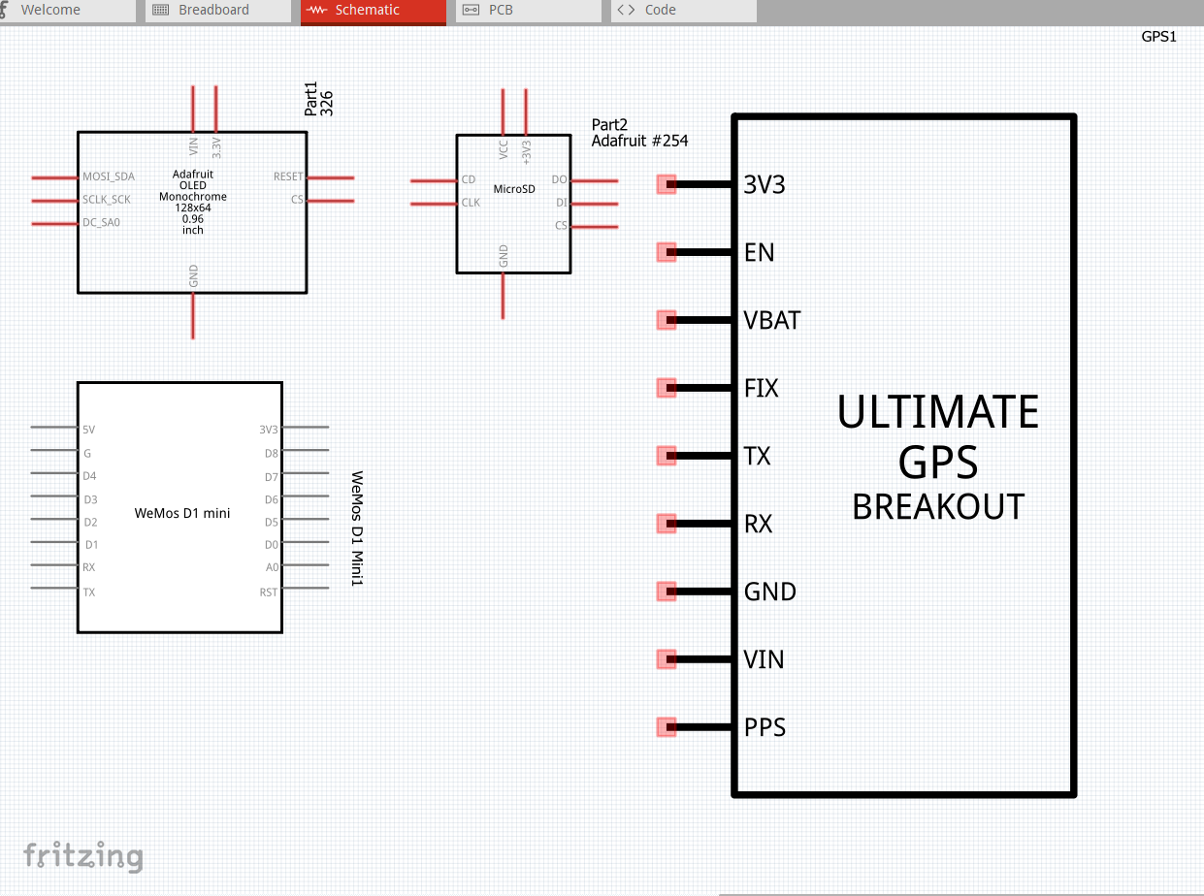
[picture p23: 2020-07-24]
Photos/Fritzing schematic incomplete .PNG

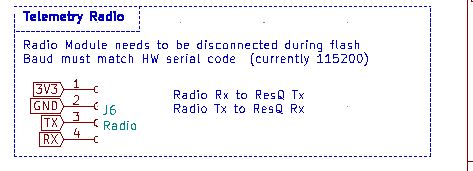
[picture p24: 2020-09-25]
Photos/Bluetooth/Schematic Connection Bluetooth.JPG

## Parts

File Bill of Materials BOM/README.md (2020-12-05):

# BOM

### Welcome to Erics land of ResQ material list (BOM)
This area is for the excel doc updated for all materials required for you to build this project.  Download BOM.xlsx above and you are all set. 

I provided Amazon and web links to all of them or grab a kit below.  Any additions please let me know. 

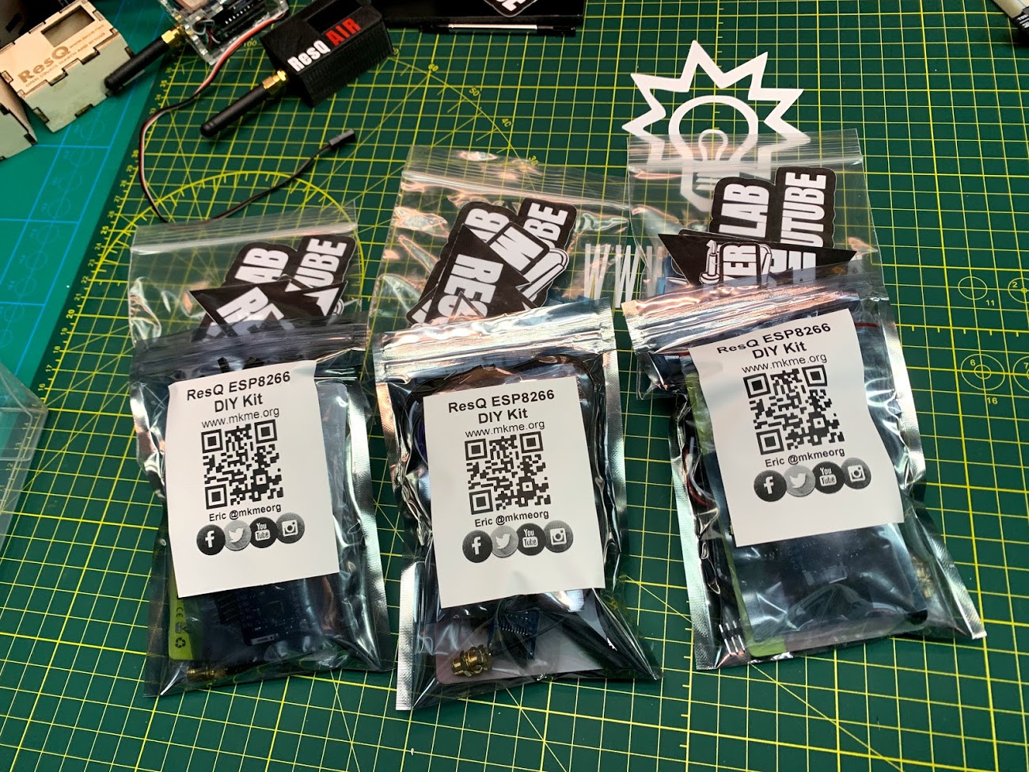
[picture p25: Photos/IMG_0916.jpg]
 

# Bill of Materials Notes

See my YouTube videos in the ResQ playlist https://www.youtube.com/playlist?list=PLxyM2a_cfnzifVreG8aKurH-9nNYl8QLr

## TIPS- 

-  I have made kits and various parts avaialble on my website here: https://store.mkme.org/?product_cat=custom

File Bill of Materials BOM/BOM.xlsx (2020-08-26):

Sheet: Air Unit
Bill of Materials (BOM):
Component | Source to Buy them | Price | Notes: | Total Cost USD | $96.69
D1 Mini Pro | https://amzn.to/2ZQArbl | $7.99
With antenna included | https://amzn.to/2ZNQEy1 | $7.99
Circuit Board (PCB) | http://store.mkme.org/product/resq-printed-circuit-board-v1-1/ | $10.00
SD Card Reader | https://amzn.to/2XPDv6B | $7.99
0.96" OLED Display | https://amzn.to/3cCHvvj | $6.99 | V1.1 PCB Files VCC at end V2.1 Ground at End
2.4 GHz Yagi Antenna | https://amzn.to/3gwLso9 | $22.45
BN220 GPS | https://amzn.to/3fYKhfO | $15.99
Servo Wire For VCC from FC | https://amzn.to/3kI5BcL | $7.00
Micro SD Card | https://amzn.to/2FjEO6y | $10.29

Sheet: Ground Unit
Bill of Materials (BOM):
Component | Source to Buy them | Price | Notes: | Total Cost USD | $119.67
D1 Mini Pro | https://amzn.to/2ZQArbl | $7.99
With antenna included | https://amzn.to/2ZNQEy1 | $7.99
Circuit Board (PCB) | http://store.mkme.org/product/resq-printed-circuit-board-v1-1/ | $10.00
SD Card Reader | https://amzn.to/2XPDv6B | $7.99
0.96" OLED Display | https://amzn.to/3cCHvvj | $6.99 | V1.1 PCB Files VCC at end V2.1 Ground at End
2.4 GHz Yagi Antenna | https://amzn.to/3gwLso9 | $22.45
BN220 GPS | https://amzn.to/3fYKhfO | $15.99
Micro SD Card | https://amzn.to/2FjEO6y | $10.29
Lipo Battery 200mah | https://amzn.to/33VoPFN | $14.99
Adafruit Power Boost Charger | https://amzn.to/3aknA4a | $14.99

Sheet: Optional Extras
Bill of Materials (BOM):
Component | Source to Buy them | Price | Notes: | Total Cost: | $29.98
SMA adapter | https://amzn.to/3ezOpT8 | 3.99 | Spare for UFLs that can get damaged
nrf24l01 | https://amzn.to/3exhePP |  | Use this for extra telemetry instead of 3DR I used
LORA Modules | https://amzn.to/2zB61ze |  | Use this for extra telemetry instead of 3DR I used
LiOn 5200mAh | https://amzn.to/3kJbMO2 | $25.99 | Lithium Ion HUUUUGE capacity but needs a diff charge control

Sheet: Nano Talon UAV
Bill of Materials (BOM):
Component | Source to Buy them | Price | Notes: | Total Cost USD : | $0.00
Nano Talon PNP Aircraft | https://www.banggood.com/ZOHD-Nano-Talon-860mm-Wingspan-AIO-HD-V-Tail-EPP-FPV-RC-Airplane-PNP-With-Gyro-p-1168297.html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
F722 Wing Flight Controller | https://amzn.to/2ZSoMsz
18650 LiOn cells | https://amzn.to/2ZSoMsz
Ill finish this another day. Im done

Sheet: Sheet5
SMA adapter | https://amzn.to/3ezOpT8
nrf24l01 | https://amzn.to/3exhePP
LORA Modules | https://amzn.to/2zB61ze
SMA adapter | https://amzn.to/3ezOpT8
nrf24l01 | https://amzn.to/3exhePP
LORA Modules | https://amzn.to/2zB61ze
Nano Talon PNP Aircraft | https://www.banggood.com/ZOHD-Nano-Talon-860mm-Wingspan-AIO-HD-V-Tail-EPP-FPV-RC-Airplane-PNP-With-Gyro-p-1168297.html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
F722 Wing Flight Controller | https://amzn.to/2ZSoMsz
18650 LiOn cells | https://amzn.to/2ZSoMsz

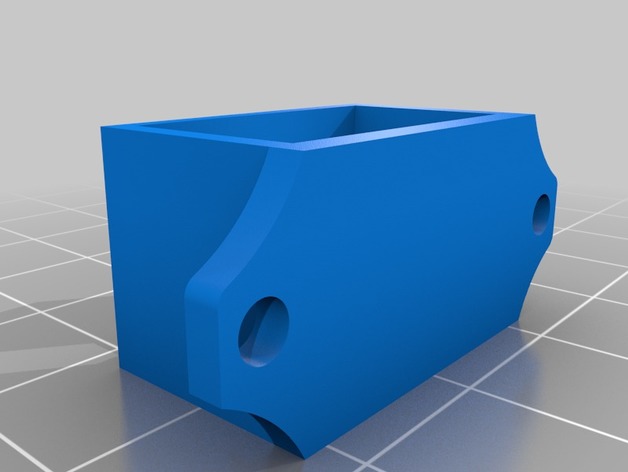
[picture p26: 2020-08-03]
Aircraft Files and Design Ref/CAD Files Parts/Nano_Talon_AKK_X2_external_mount/images/e6169ca9910e4d13ceca58a9d32e4528_preview_featured.jpg

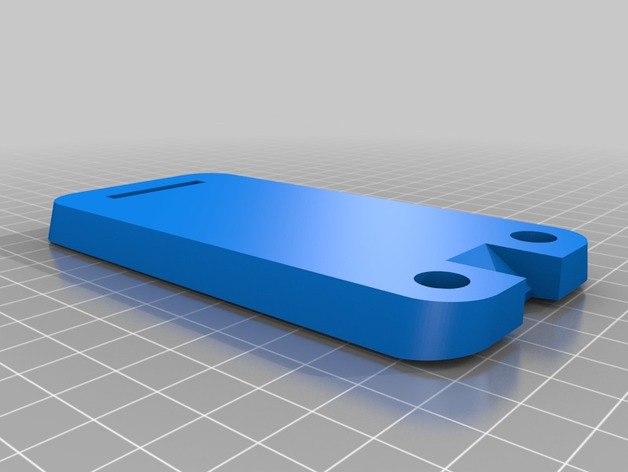
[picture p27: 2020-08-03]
Aircraft Files and Design Ref/CAD Files Parts/Nano_Talon_Bottom_Hatch/images/8a21a38b07a1ea7f48b0e1492d407cef_preview_featured.jpg

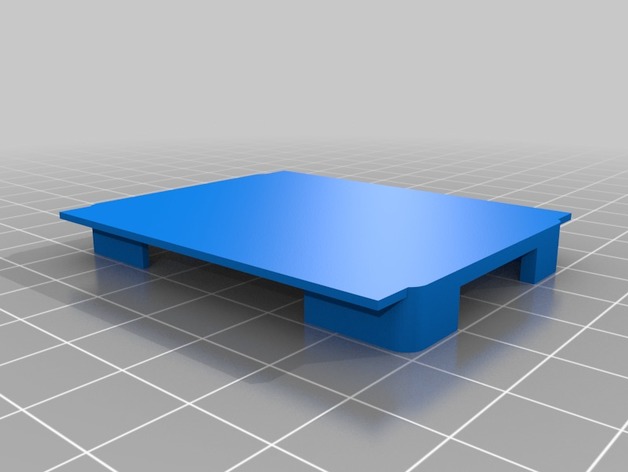
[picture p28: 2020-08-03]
Aircraft Files and Design Ref/CAD Files Parts/Matek_F722w_holder/images/af881bda1037669822e9a27e0b8accae_preview_featured.jpg

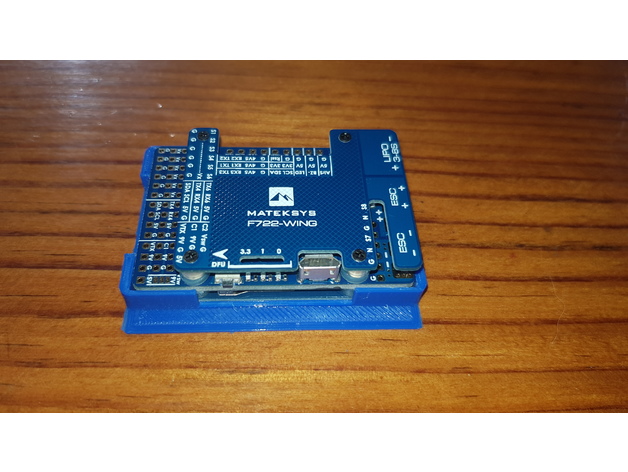
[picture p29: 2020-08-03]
Aircraft Files and Design Ref/CAD Files Parts/Matek_F722w_holder/images/701aa117f2e8ba2d1e824a54d8214bf0_preview_featured.jpg

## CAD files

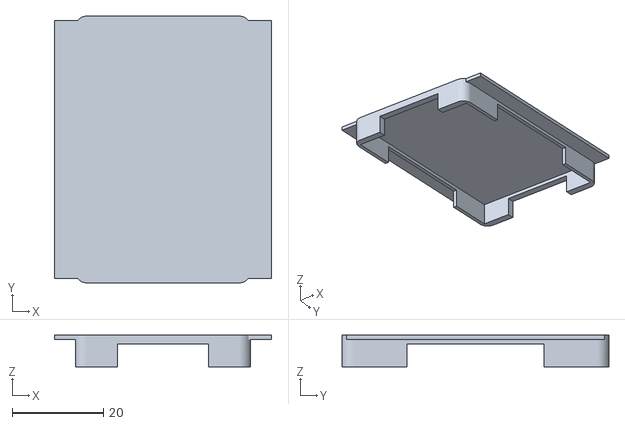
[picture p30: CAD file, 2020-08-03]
Aircraft Files and Design Ref/CAD Files Parts/F722_wing_fc_holder.stl
47.5 x 58.4 x 7.00

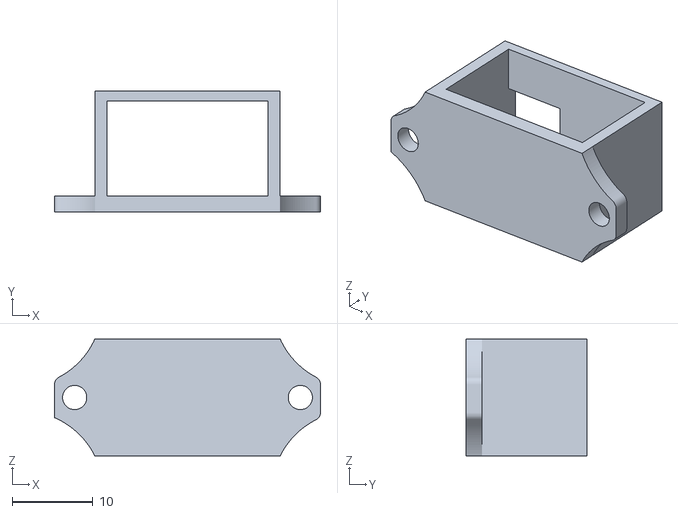
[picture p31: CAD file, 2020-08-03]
Aircraft Files and Design Ref/CAD Files Parts/Nano_Talon_AKK_X2_external_mount/files/VTX-mount5.stl
33.0 x 15.0 x 14.5

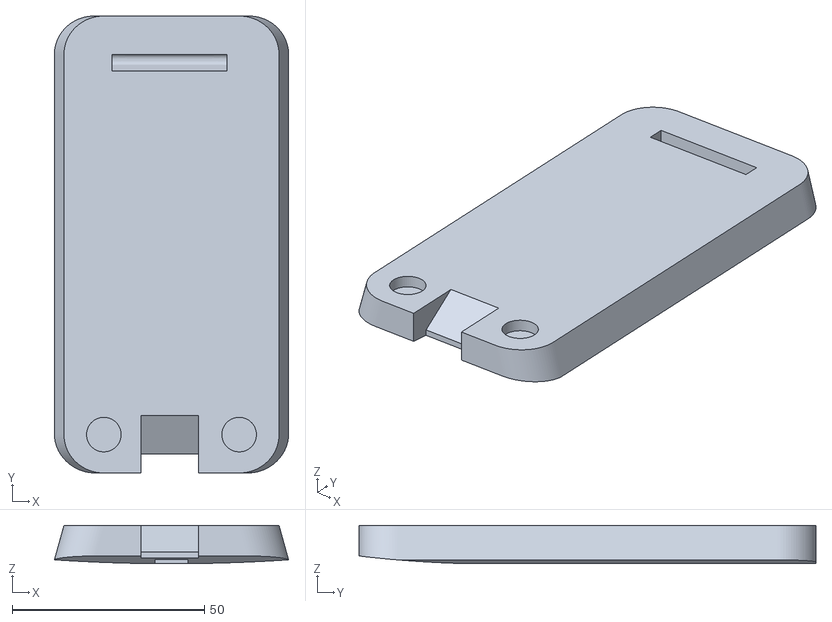
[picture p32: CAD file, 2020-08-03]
Aircraft Files and Design Ref/CAD Files Parts/Nano_Talon_Bottom_Hatch/files/Hatch1.stl
61.0 x 119.0 x 10.0

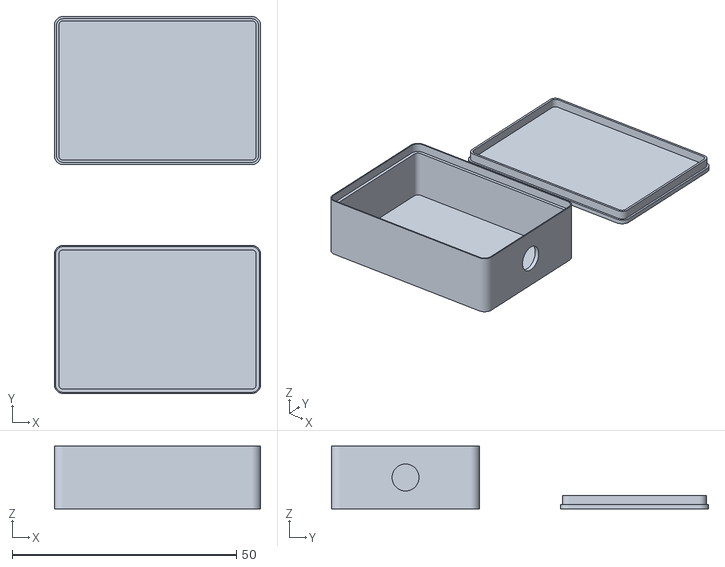
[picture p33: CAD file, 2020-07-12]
Enclsoure CAD Files/3D Models/Air Unit Enclosure/V1.2/snap_box.stl
46.0 x 84.0 x 14.0

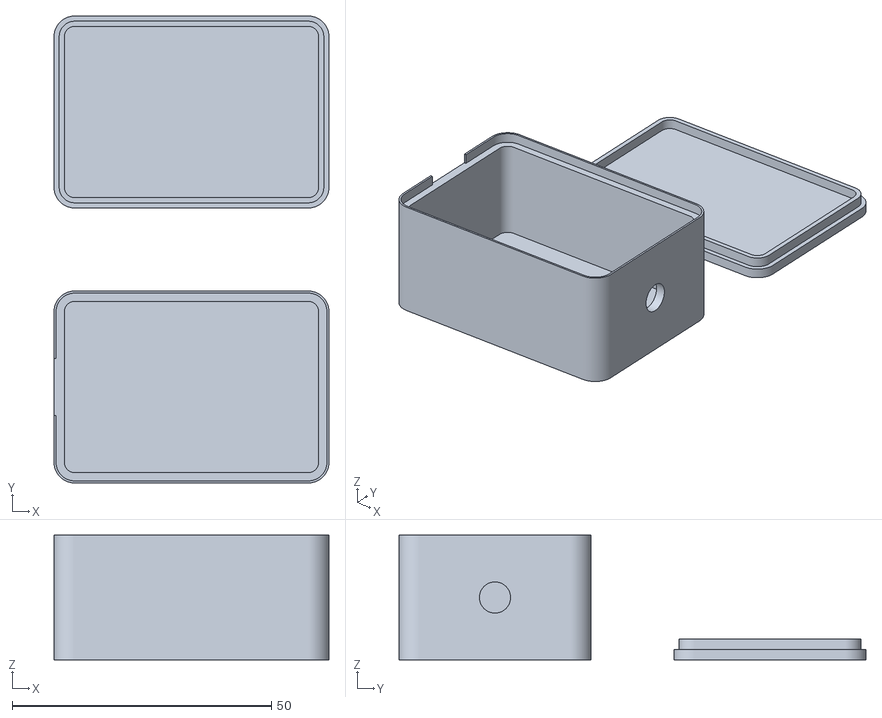
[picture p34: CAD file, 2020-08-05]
Enclsoure CAD Files/3D Models/Air Unit Enclosure/V1.3 Abandoned/snap_box.stl
53.0 x 90.0 x 24.0

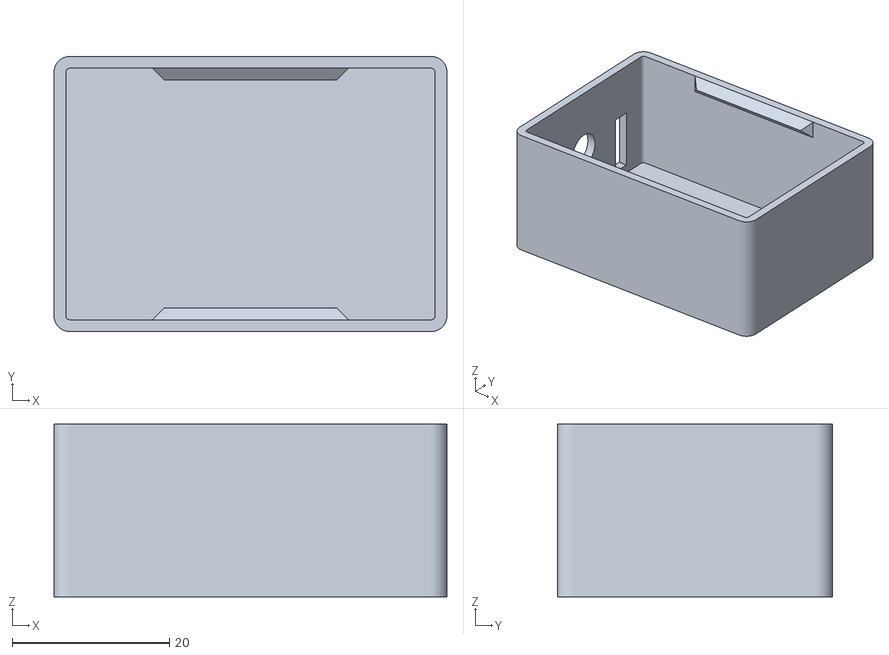
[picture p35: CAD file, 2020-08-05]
Enclsoure CAD Files/3D Models/Air Unit Enclosure/V1.4 Fusion 360/Case.stl
50.0 x 35.0 x 22.0

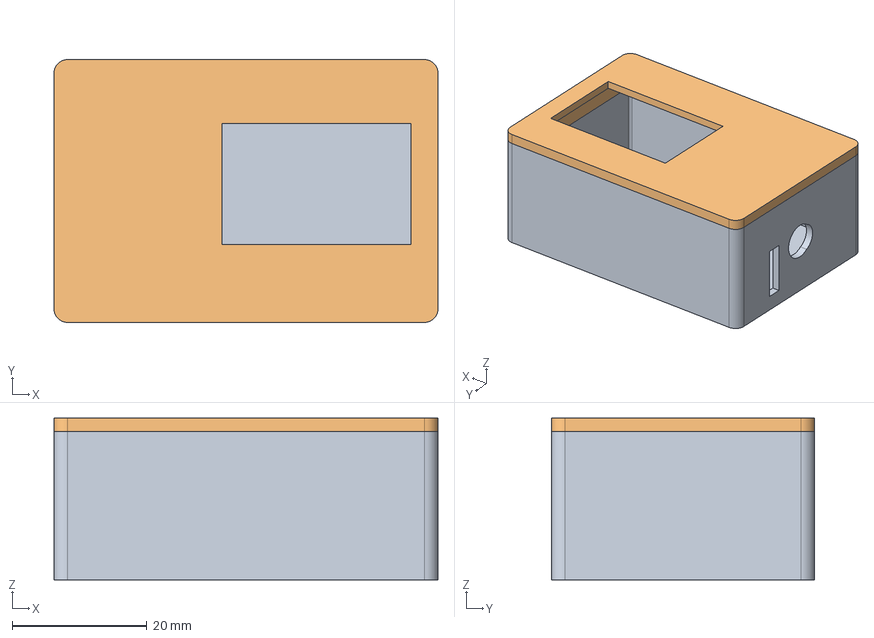
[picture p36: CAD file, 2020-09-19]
Enclsoure CAD Files/3D Models/Air Unit Enclosure/V1.6 Longer and wider yet/Air Enclosure.step
57.0 x 39.0 x 24.0 mm
Case
Top Cover

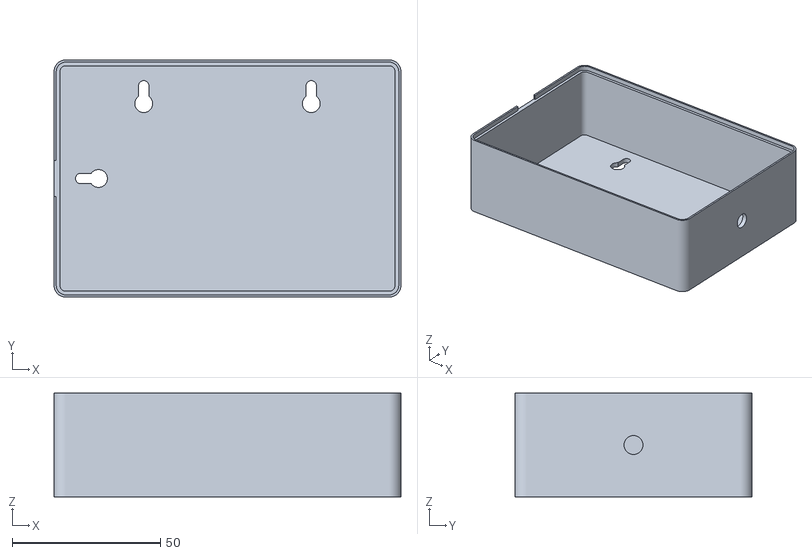
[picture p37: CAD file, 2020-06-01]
Enclsoure CAD Files/3D Models/Ground Unit Enclosure/V1.1/My+Customized+Parametric+Project+Box/files/snap_box_box20200601-60-507ek2.stl
117.0 x 80.0 x 35.0

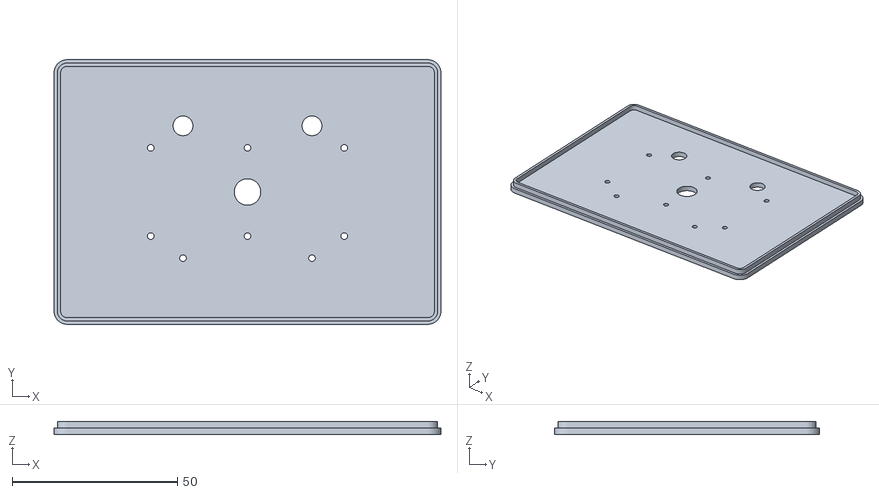
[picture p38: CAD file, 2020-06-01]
Enclsoure CAD Files/3D Models/Ground Unit Enclosure/V1.1/snap_box_top20200601-60-1631z0u.stl
117.0 x 80.0 x 4.00

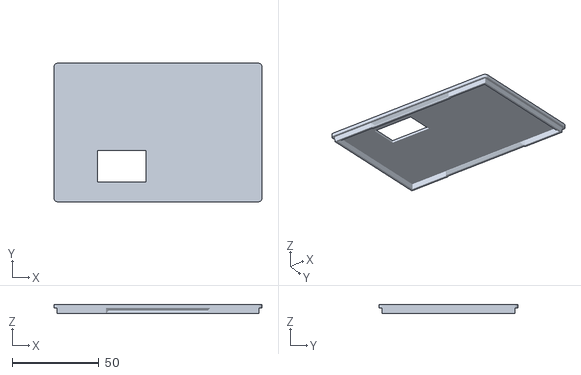
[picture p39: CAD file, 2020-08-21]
Enclsoure CAD Files/3D Models/Ground Unit Enclosure/V1.2 Fusion 360/Top Cover 1.2 .stl
120.0 x 80.0 x 5.00

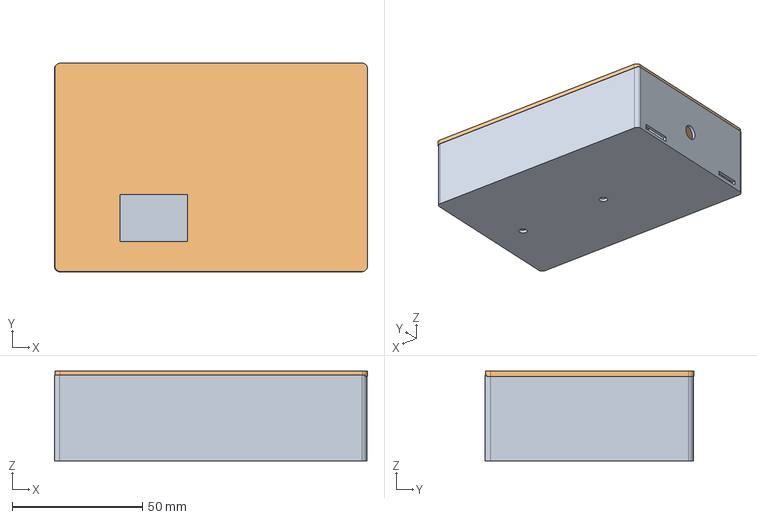
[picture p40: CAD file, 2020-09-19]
Enclsoure CAD Files/3D Models/Ground Unit Enclosure/V1.3 Narrowed OLED Cutout/Ground Enclosure.step
120.2 x 80.1 x 34.5 mm
Case
Top Cover

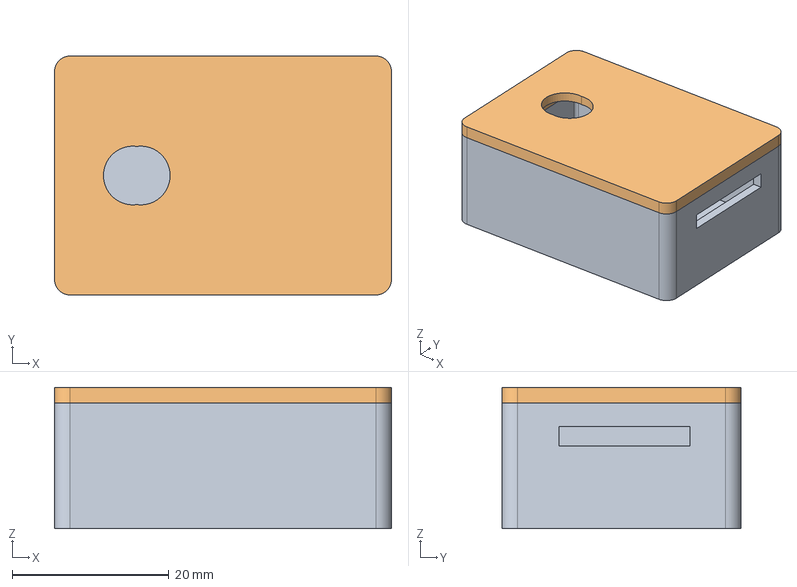
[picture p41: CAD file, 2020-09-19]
Enclsoure CAD Files/ResQ Camera Enclosures/3D/V1.1/Camera Enclosure.step
43.0 x 30.5 x 18.0 mm
Case
Top Cover

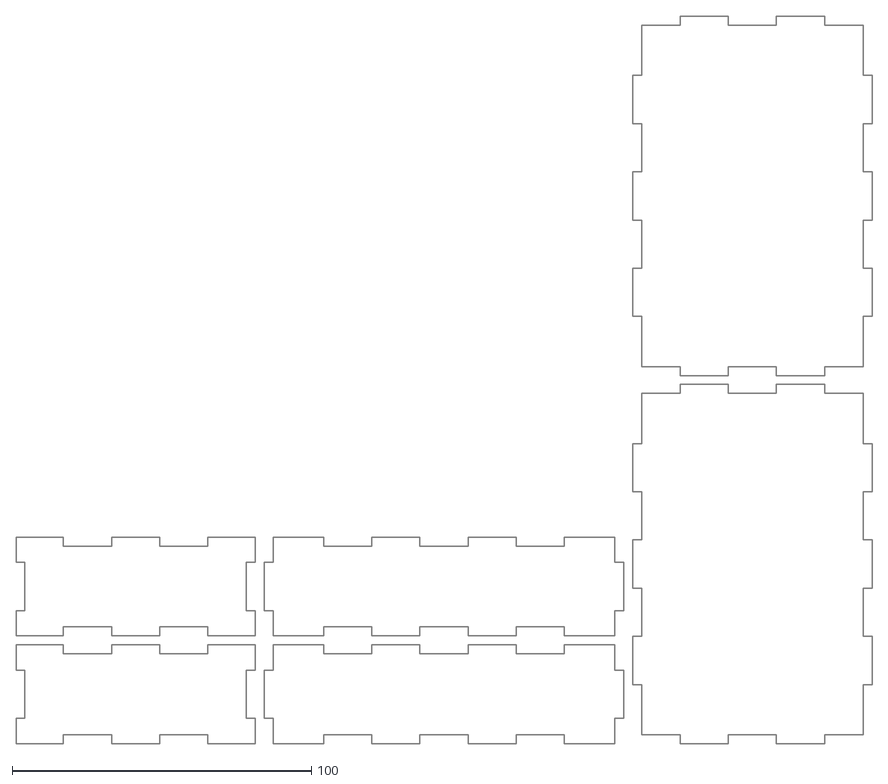
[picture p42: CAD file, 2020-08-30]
Enclsoure CAD Files/ResQ Sentry Enclosure/2D/box.dxf
286.0 x 243.0

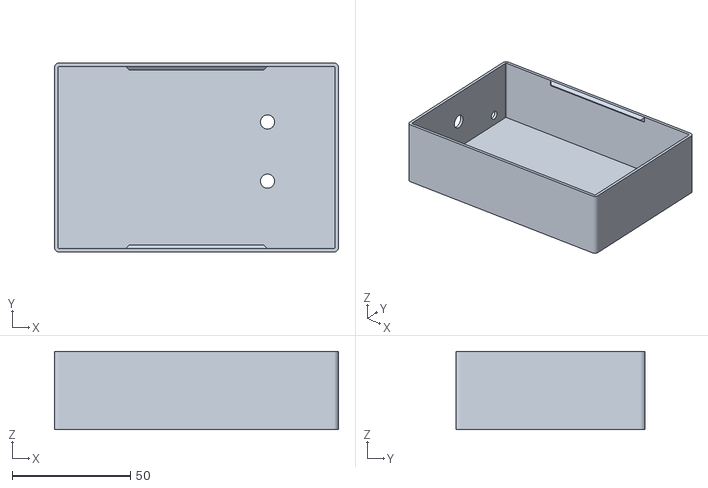
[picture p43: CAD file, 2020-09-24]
Enclsoure CAD Files/ResQ Sentry Enclosure/3D/Case.stl
120.0 x 80.0 x 33.0

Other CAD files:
Enclsoure CAD Files/2D Models/Air Unit/V1.1 Air Unit Enclosure Laser Cut Version/box.dxf
Enclsoure CAD Files/2D Models/Air Unit/V1.2 Air Unit Changed to outside dimensios plus 3mm/box.dxf
Enclsoure CAD Files/2D Models/Air Unit/V1.3 Air Unit Sclaed back down to 1.1 plus 3mm height/box.dxf
Enclsoure CAD Files/2D Models/Air Unit/V1.4 2mm Higher/box.dxf
Enclsoure CAD Files/3D Models/Air Unit Enclosure/V1.2/snap_box.scad
Enclsoure CAD Files/3D Models/Air Unit Enclosure/V1.3 Abandoned/snap_box.scad
Aircraft Files and Design Ref/CAD Files Parts/Nano_Talon_Bottom_Hatch/files/Hatch2.stl
Enclsoure CAD Files/3D Models/Air Unit Enclosure/V1.1/snap_box.stl
Enclsoure CAD Files/3D Models/Air Unit Enclosure/V1.3 Abandoned/Body1.stl
Enclsoure CAD Files/3D Models/Air Unit Enclosure/V1.4 Fusion 360/Air Unit Enclosure v9.f3d
Enclsoure CAD Files/3D Models/Air Unit Enclosure/V1.4 Fusion 360/Top Cover.stl
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

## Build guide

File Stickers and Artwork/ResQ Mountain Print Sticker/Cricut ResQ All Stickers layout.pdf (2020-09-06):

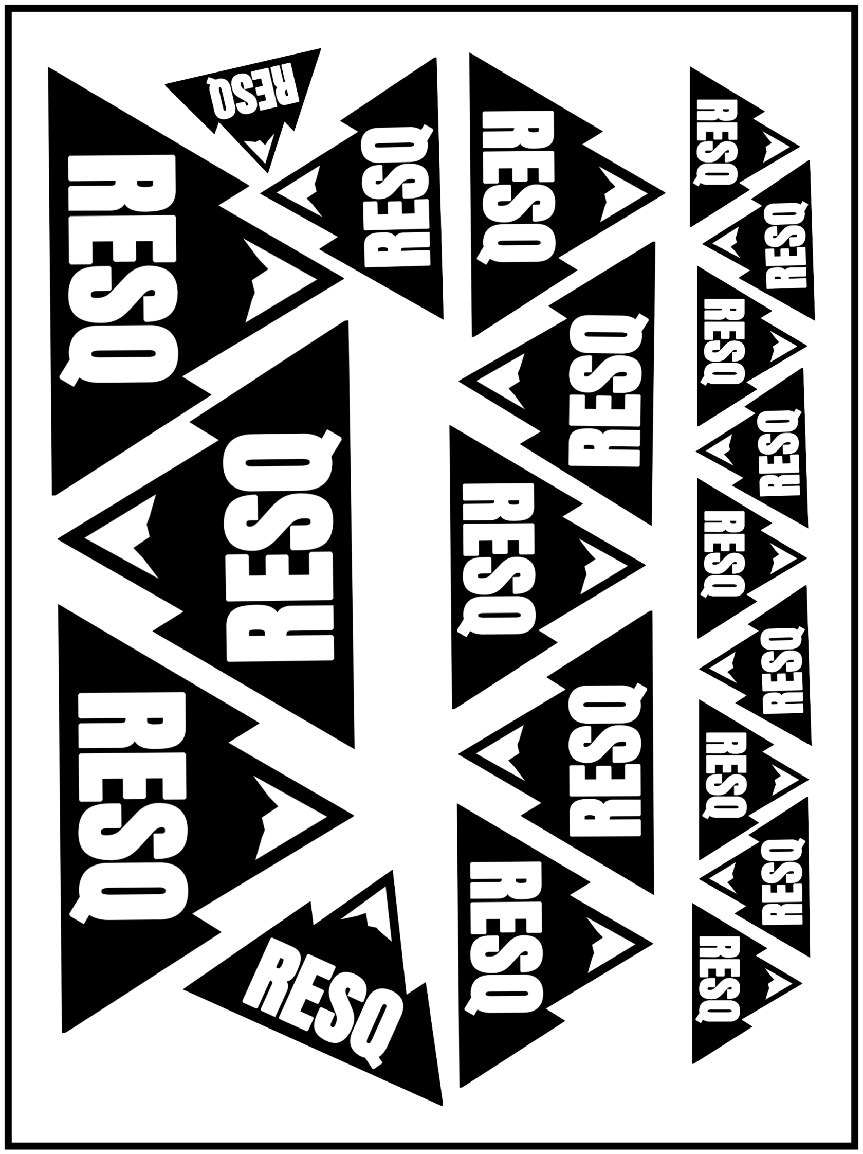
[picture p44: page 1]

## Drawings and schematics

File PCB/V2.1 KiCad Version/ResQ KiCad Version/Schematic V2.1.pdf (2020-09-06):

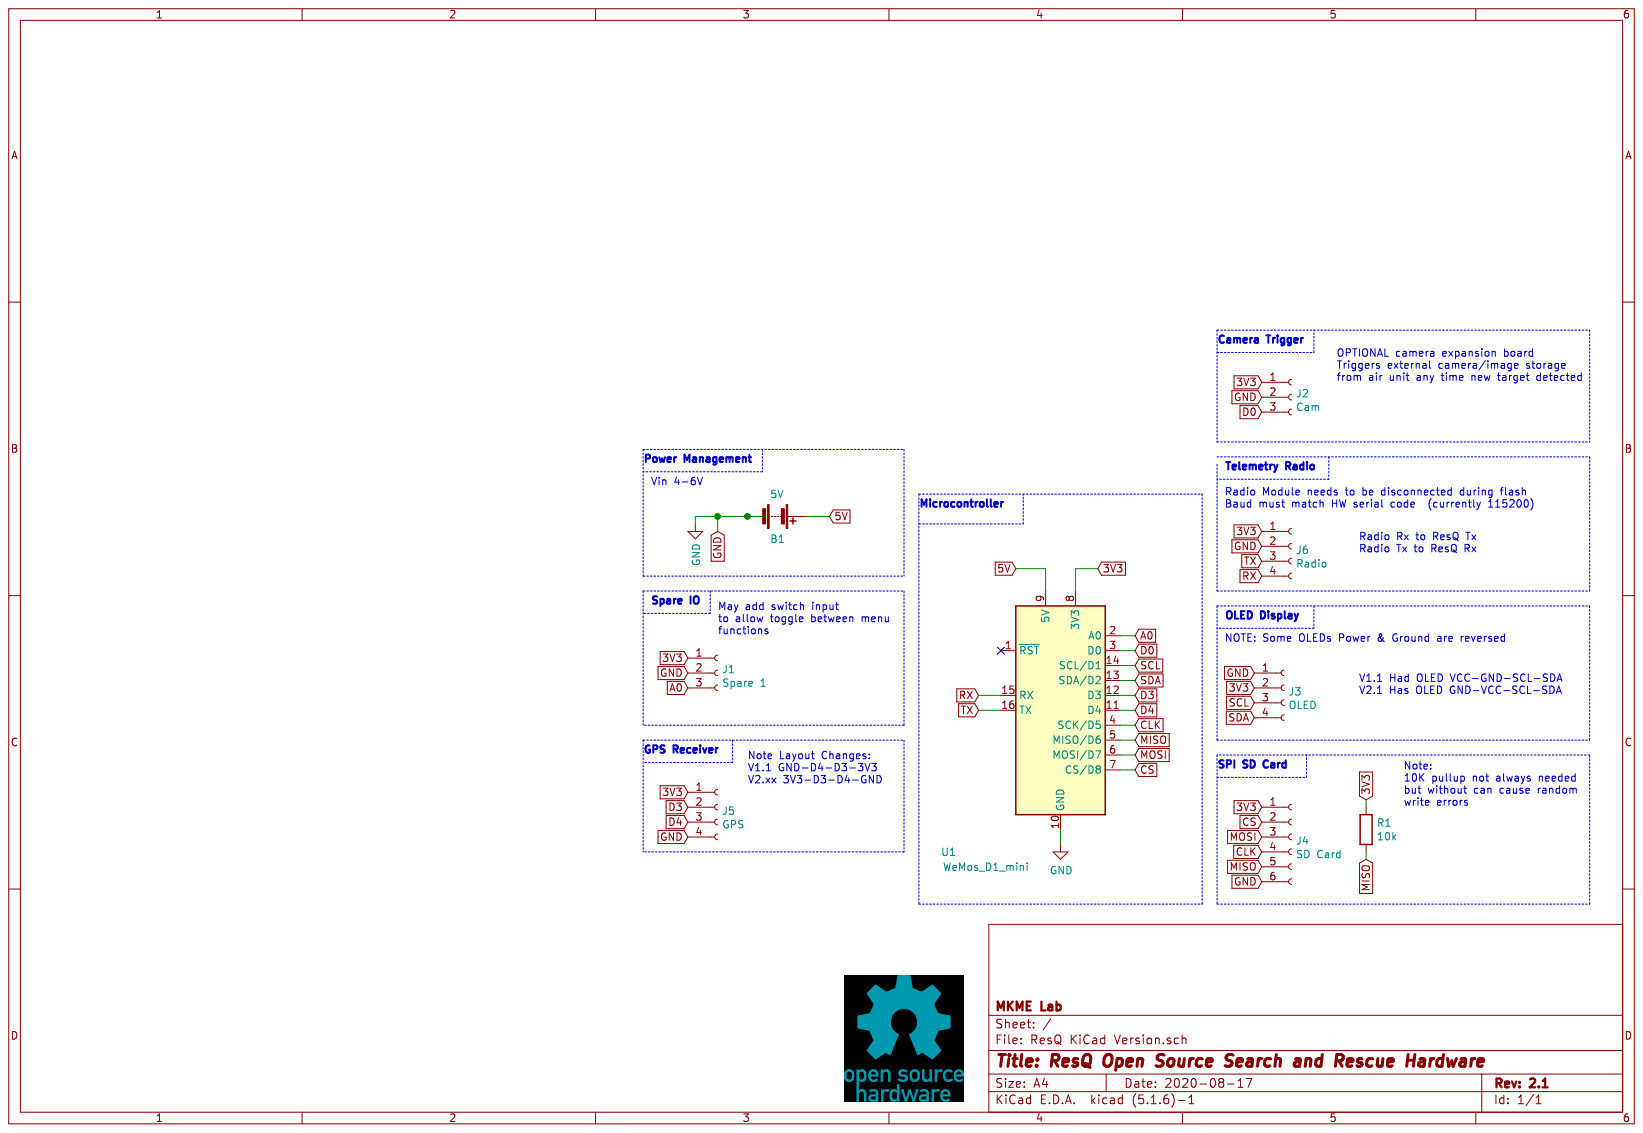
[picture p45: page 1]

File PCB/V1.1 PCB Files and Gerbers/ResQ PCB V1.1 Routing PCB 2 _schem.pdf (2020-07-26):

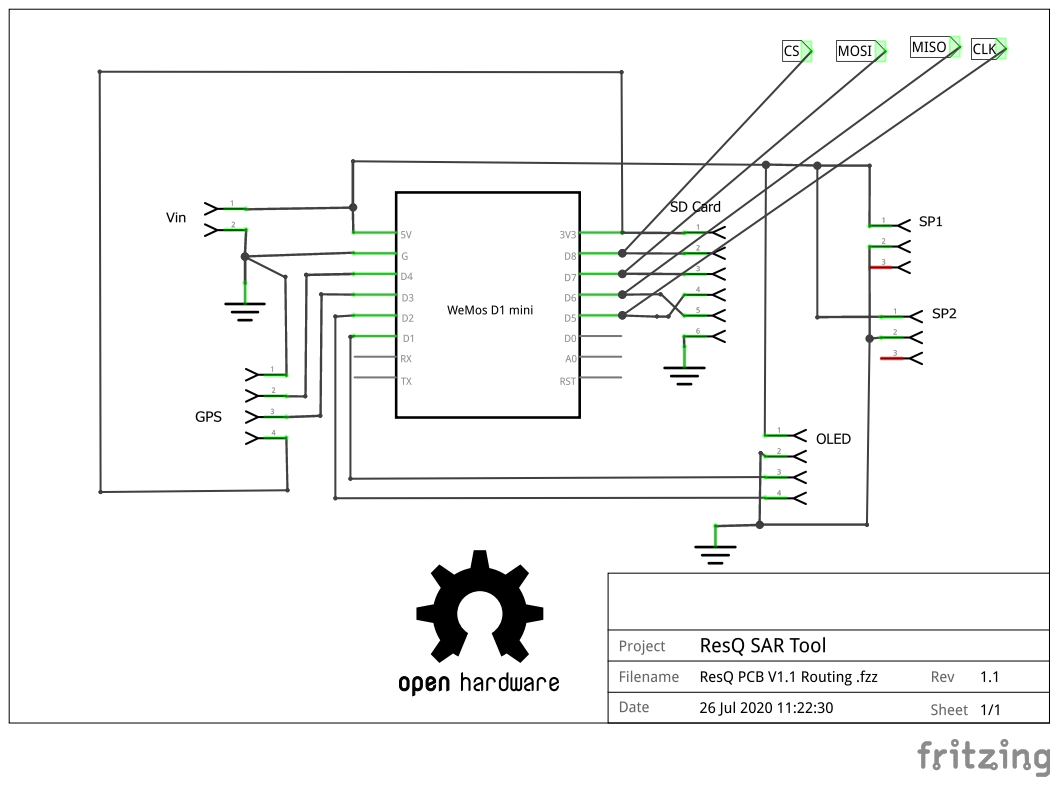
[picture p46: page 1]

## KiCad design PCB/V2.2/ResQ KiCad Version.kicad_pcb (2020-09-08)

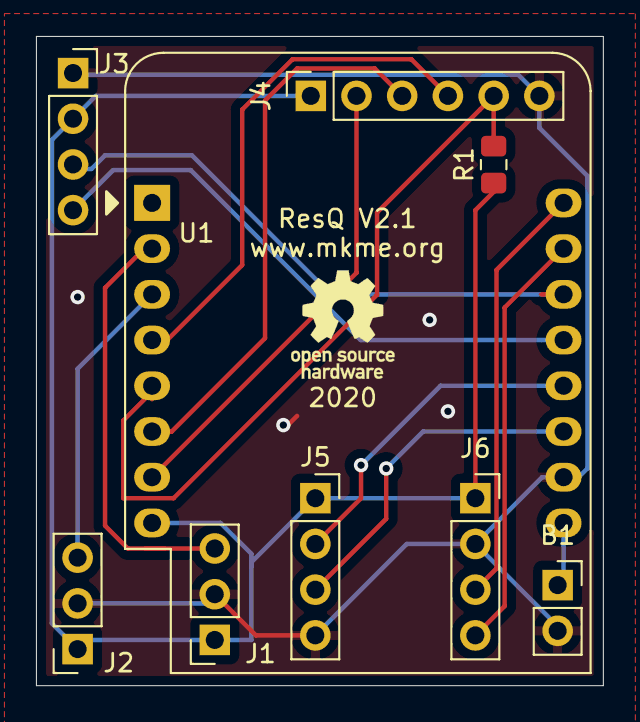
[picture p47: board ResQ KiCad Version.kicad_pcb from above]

Board: 2 copper layers, 31.5 x 36.1 mm, 9 parts (0 on the bottom side), 15 nets.

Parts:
B1: 5V; PinSocket_1x02_P2.54mm_Vertical
J1: SP1; PinSocket_1x03_P2.54mm_Vertical
J2: Cam; PinSocket_1x03_P2.54mm_Vertical
J3: OLED; PinSocket_1x04_P2.54mm_Vertical
J4: SD Card; PinSocket_1x06_P2.54mm_Vertical
J5: GPS; PinSocket_1x04_P2.54mm_Vertical
J6: Radio; PinSocket_1x04_P2.54mm_Vertical
R1: 10k; R_0805_2012Metric_Pad1.15x1.40mm_HandSolder
U1: WeMos; WEMOS_D1_mini_light

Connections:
3V3: J1.1, J2.1, J3.2, J4.1, J5.1, J6.1, R1.1, U1.8
5V: B1.1, U1.9
A0: J1.3, U1.2
CLK: J4.4, U1.4
CS: J4.2, U1.7
D0: J2.3, U1.3
D3: J5.2, U1.12
D4: J5.3, U1.11
GND: B1.2, J1.2, J2.2, J3.1, J4.6, J5.4, J6.2, U1.10
MISO: J4.5, R1.2, U1.5
MOSI: J4.3, U1.6
RX: J6.4, U1.15
SCL: J3.3, U1.14
SDA: J3.4, U1.13
TX: J6.3, U1.16

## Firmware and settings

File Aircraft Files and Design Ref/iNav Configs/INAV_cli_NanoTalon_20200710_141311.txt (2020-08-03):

dump all

# version
# INAV/MATEKF722SE 2.4.0 Feb 11 2020 / 22:53:38 (bcd4caef9)
# GCC-8.2.1 20181213 (release) [gcc-8-branch revision 267074]

# start the command batch
batch start

# resources

# mixer

mmix reset

mmix 0  1.000  0.000  0.000  0.000

# servo mix
smix reset

smix 0 2 0 -100 0 -1
smix 1 3 1 -100 0 -1
smix 2 4 1 100 0 -1
smix 3 3 2 75 0 -1
smix 4 4 2 75 0 -1

# servo
servo 0 1000 2000 1500 100
servo 1 1000 2000 1500 100
servo 2 1000 2000 1529 100
servo 3 1000 2000 1567 100
servo 4 1000 2000 1431 100
servo 5 1000 2000 1500 100
servo 6 1000 2000 1500 100
servo 7 1000 2000 1500 100
servo 8 1000 2000 1500 100
servo 9 1000 2000 1500 100
servo 10 1000 2000 1500 100
servo 11 1000 2000 1500 100
servo 12 1000 2000 1500 100
servo 13 1000 2000 1500 100
servo 14 1000 2000 1500 100
servo 15 1000 2000 1500 100

# logic
logic 0 0 0 0 0 0 0 0
logic 1 0 0 0 0 0 0 0
logic 2 0 0 0 0 0 0 0
logic 3 0 0 0 0 0 0 0
logic 4 0 0 0 0 0 0 0
logic 5 0 0 0 0 0 0 0
logic 6 0 0 0 0 0 0 0
logic 7 0 0 0 0 0 0 0
logic 8 0 0 0 0 0 0 0
logic 9 0 0 0 0 0 0 0
logic 10 0 0 0 0 0 0 0
logic 11 0 0 0 0 0 0 0
logic 12 0 0 0 0 0 0 0
logic 13 0 0 0 0 0 0 0
logic 14 0 0 0 0 0 0 0
logic 15 0 0 0 0 0 0 0

# gf
gf 0 0 -1 0 0 0 0
gf 1 0 -1 0 0 0 0
gf 2 0 -1 0 0 0 0
gf 3 0 -1 0 0 0 0
gf 4 0 -1 0 0 0 0
gf 5 0 -1 0 0 0 0
gf 6 0 -1 0 0 0 0
gf 7 0 -1 0 0 0 0

# feature
feature -THR_VBAT_COMP
feature -VBAT
feature -TX_PROF_SEL
feature -BAT_PROF_AUTOSWITCH
feature -MOTOR_STOP
feature -DYNAMIC_FILTERS
feature -SOFTSERIAL
feature -GPS
feature -RPM_FILTERS
feature -TELEMETRY
feature -CURRENT_METER
feature -3D
feature -RSSI_ADC
feature -LED_STRIP
feature -DASHBOARD
feature -BLACKBOX
feature -TRANSPONDER
feature -AIRMODE
feature -SUPEREXPO
feature -VTX
feature -PWM_SERVO_DRIVER
feature -PWM_OUTPUT_ENABLE
feature -OSD
feature -FW_LAUNCH
feature VBAT
feature TX_PROF_SEL
feature MOTOR_STOP
feature SOFTSERIAL
feature GPS
feature TELEMETRY
feature CURRENT_METER
feature DASHBOARD
feature BLACKBOX
feature AIRMODE
feature PWM_OUTPUT_ENABLE
feature OSD

# beeper
beeper RUNTIME_CALIBRATION
beeper HW_FAILURE
beeper RX_LOST
beeper RX_LOST_LANDING
beeper DISARMING
beeper ARMING
beeper ARMING_GPS_FIX
beeper BAT_CRIT_LOW
beeper BAT_LOW
beeper GPS_STATUS
beeper RX_SET
beeper ACTION_SUCCESS
beeper ACTION_FAIL
beeper READY_BEEP
beeper MULTI_BEEPS
beeper DISARM_REPEAT
beeper ARMED
beeper SYSTEM_INIT
beeper -ON_USB
beeper LAUNCH_MODE
beeper CAM_CONNECTION_OPEN
beeper CAM_CONNECTION_CLOSED

# map
map AETR

# serial
serial 20 1 115200 115200 0 115200
serial 0 1 57600 115200 0 115200
serial 1 64 115200 115200 0 115200
serial 2 2 115200 115200 0 115200
serial 3 4096 115200 115200 0 115200
serial 5 1024 115200 115200 0 115200
serial 30 0 115200 115200 0 115200

# led
led 0 0,0::C:0
led 1 0,0::C:0
led 2 0,0::C:0
led 3 0,0::C:0
led 4 0,0::C:0
led 5 0,0::C:0
led 6 0,0::C:0
led 7 0,0::C:0
led 8 0,0::C:0
led 9 0,0::C:0
led 10 0,0::C:0
led 11 0,0::C:0
led 12 0,0::C:0
led 13 0,0::C:0
led 14 0,0::C:0
led 15 0,0::C:0
led 16 0,0::C:0
led 17 0,0::C:0
led 18 0,0::C:0
led 19 0,0::C:0
led 20 0,0::C:0
led 21 0,0::C:0
led 22 0,0::C:0
led 23 0,0::C:0
led 24 0,0::C:0
led 25 0,0::C:0
led 26 0,0::C:0
led 27 0,0::C:0
led 28 0,0::C:0
led 29 0,0::C:0
led 30 0,0::C:0
led 31 0,0::C:0

# color
color 0 0,0,0
color 1 0,255,255
color 2 0,0,255
color 3 30,0,255
color 4 60,0,255
color 5 90,0,255
color 6 120,0,255
color 7 150,0,255
color 8 180,0,255
color 9 210,0,255
color 10 240,0,255
color 11 270,0,255
color 12 300,0,255
color 13 330,0,255
color 14 0,0,0
color 15 0,0,0

# mode_color
mode_color 0 0 1
mode_color 0 1 11
mode_color 0 2 2
mode_color 0 3 13
mode_color 0 4 10
mode_color 0 5 3
mode_color 1 0 5
mode_color 1 1 11
mode_color 1 2 3
mode_color 1 3 13
mode_color 1 4 10
mode_color 1 5 3
mode_color 2 0 10
mode_color 2 1 11
mode_color 2 2 4
mode_color 2 3 13
mode_color 2 4 10
mode_color 2 5 3
mode_color 3 0 8
mode_color 3 1 11
mode_color 3 2 4
mode_color 3 3 13
mode_color 3 4 10
mode_color 3 5 3
mode_color 4 0 7
mode_color 4 1 11
mode_color 4 2 3
mode_color 4 3 13
mode_color 4 4 10
mode_color 4 5 3
mode_color 5 0 9
mode_color 5 1 11
mode_color 5 2 2
mode_color 5 3 13
mode_color 5 4 10
mode_color 5 5 3
mode_color 6 0 6
mode_color 6 1 10
mode_color 6 2 1
mode_color 6 3 0
mode_color 6 4 0
mode_color 6 5 2
mode_color 6 6 3
mode_color 6 7 6
mode_color 6 8 0
mode_color 6 9 0
mode_color 6 10 0

# aux
aux 0 0 0 1700 2100
aux 1 2 1 1300 1700
aux 2 3 1 900 1300
aux 3 3 4 1300 1700
aux 4 9 4 1300 1700
aux 5 8 4 1700 2100
aux 6 8 3 1300 1700
aux 7 19 3 1700 2100
aux 8 35 1 900 1300
aux 9 10 1 1700 2100
aux 10 14 3 1300 1700
aux 11 27 2 1700 2100
aux 12 28 2 1300 1700
aux 13 0 0 900 900
aux 14 0 0 900 900
aux 15 0 0 900 900
aux 16 0 0 900 900
aux 17 0 0 900 900
aux 18 0 0 900 900
aux 19 0 0 900 900

# adjrange
adjrange 0 0 0 900 900 0 0
adjrange 1 0 0 900 900 0 0
adjrange 2 0 0 900 900 0 0
adjrange 3 0 0 900 900 0 0
adjrange 4 0 0 900 900 0 0
adjrange 5 0 0 900 900 0 0
adjrange 6 0 0 900 900 0 0
adjrange 7 0 0 900 900 0 0
adjrange 8 0 0 900 900 0 0
adjrange 9 0 0 900 900 0 0
adjrange 10 0 0 900 900 0 0
adjrange 11 0 0 900 900 0 0

# rxrange
rxrange 0 1000 2000
rxrange 1 1000 2000
rxrange 2 1000 2000
rxrange 3 1000 2000

# temp_sensor
temp_sensor 0 0 0 0 0 0 
temp_sensor 1 0 0 0 0 0 
temp_sensor 2 0 0 0 0 0 
temp_sensor 3 0 0 0 0 0 
temp_sensor 4 0 0 0 0 0 
temp_sensor 5 0 0 0 0 0 
temp_sensor 6 0 0 0 0 0 
temp_sensor 7 0 0 0 0 0 

# wp
#wp 0 invalid
wp 0 0 0 0 0 0 0
wp 1 0 0 0 0 0 0
wp 2 0 0 0 0 0 0
wp 3 0 0 0 0 0 0
wp 4 0 0 0 0 0 0
wp 5 0 0 0 0 0 0
wp 6 0 0 0 0 0 0
wp 7 0 0 0 0 0 0
wp 8 0 0 0 0 0 0
wp 9 0 0 0 0 0 0
wp 10 0 0 0 0 0 0
wp 11 0 0 0 0 0 0
wp 12 0 0 0 0 0 0
wp 13 0 0 0 0 0 0
wp 14 0 0 0 0 0 0
wp 15 0 0 0 0 0 0
wp 16 0 0 0 0 0 0
wp 17 0 0 0 0 0 0
wp 18 0 0 0 0 0 0
wp 19 0 0 0 0 0 0
wp 20 0 0 0 0 0 0
wp 21 0 0 0 0 0 0
wp 22 0 0 0 0 0 0
wp 23 0 0 0 0 0 0
wp 24 0 0 0 0 0 0
wp 25 0 0 0 0 0 0
wp 26 0 0 0 0 0 0
wp 27 0 0 0 0 0 0
wp 28 0 0 0 0 0 0
wp 29 0 0 0 0 0 0
wp 30 0 0 0 0 0 0
wp 31 0 0 0 0 0 0
wp 32 0 0 0 0 0 0
wp 33 0 0 0 0 0 0
wp 34 0 0 0 0 0 0
wp 35 0 0 0 0 0 0
wp 36 0 0 0 0 0 0
wp 37 0 0 0 0 0 0
wp 38 0 0 0 0 0 0
wp 39 0 0 0 0 0 0
wp 40 0 0 0 0 0 0
wp 41 0 0 0 0 0 0
wp 42 0 0 0 0 0 0
wp 43 0 0 0 0 0 0
wp 44 0 0 0 0 0 0
wp 45 0 0 0 0 0 0
wp 46 0 0 0 0 0 0
wp 47 0 0 0 0 0 0
wp 48 0 0 0 0 0 0
wp 49 0 0 0 0 0 0
wp 50 0 0 0 0 0 0
wp 51 0 0 0 0 0 0
wp 52 0 0 0 0 0 0
wp 53 0 0 0 0 0 0
wp 54 0 0 0 0 0 0
wp 55 0 0 0 0 0 0
wp 56 0 0 0 0 0 0
wp 57 0 0 0 0 0 0
wp 58 0 0 0 0 0 0
wp 59 0 0 0 0 0 0
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

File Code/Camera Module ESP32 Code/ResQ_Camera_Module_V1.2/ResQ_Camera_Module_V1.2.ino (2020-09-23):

/*

Erics Open Source ResQ Search and Rescue Tool
My Youtube Channel  : http://www.youtube.com/mkmeorg
If you use this code or personalize it etc- please consider sharing it back with the world via the forum at http://www.mkme.org/forum
Website, Forum http://mkme.org
Chat with Me: Discord http://mkme.org/discord
Store http://mkme.org/store
  

This work is licensed under a Creative Commons Attribution-NonCommercial 4.0 International License.
https://creativecommons.org/licenses/by-nc/4.0/ 
 
V1.1 Aug 2020:
See original project from Rui here at https://RandomNerdTutorials.com/esp32-cam-take-photo-save-microsd-card
   - Select Board "AI Thinker ESP32-CAM"
   - GPIO 0 must be connected to GND to upload a sketch
   - After connecting GPIO 0 to GND, press the ESP32-CAM on-board RESET button to put your board in flashing mode
 
*/



#include "esp_camera.h"
#include "Arduino.h"
#include "FS.h"                // SD Card ESP32
#include "SD_MMC.h"            // SD Card ESP32
#include "soc/soc.h"           // Disable brownour problems
#include "soc/rtc_cntl_reg.h"  // Disable brownour problems
#include "driver/rtc_io.h"
#include <EEPROM.h>            // read and write from flash memory

// define the number of bytes you want to access
#define EEPROM_SIZE 1

// Pin definition for CAMERA_MODEL_AI_THINKER
#define PWDN_GPIO_NUM     32
#define RESET_GPIO_NUM    -1
#define XCLK_GPIO_NUM      0
#define SIOD_GPIO_NUM     26
#define SIOC_GPIO_NUM     27

#define Y9_GPIO_NUM       35
#define Y8_GPIO_NUM       34
#define Y7_GPIO_NUM       39
#define Y6_GPIO_NUM       36
#define Y5_GPIO_NUM       21
#define Y4_GPIO_NUM       19
#define Y3_GPIO_NUM       18
#define Y2_GPIO_NUM        5
#define VSYNC_GPIO_NUM    25
#define HREF_GPIO_NUM     23
#define PCLK_GPIO_NUM     22

int pictureNumber = 0;

void setup() {
  WRITE_PERI_REG(RTC_CNTL_BROWN_OUT_REG, 0); //disable brownout detector
 
  Serial.begin(115200);
  //Serial.setDebugOutput(true);
  //Serial.println();
  
  camera_config_t config;
  config.ledc_channel = LEDC_CHANNEL_0;
  config.ledc_timer = LEDC_TIMER_0;
  config.pin_d0 = Y2_GPIO_NUM;
  config.pin_d1 = Y3_GPIO_NUM;
  config.pin_d2 = Y4_GPIO_NUM;
  config.pin_d3 = Y5_GPIO_NUM;
  config.pin_d4 = Y6_GPIO_NUM;
  config.pin_d5 = Y7_GPIO_NUM;
  config.pin_d6 = Y8_GPIO_NUM;
  config.pin_d7 = Y9_GPIO_NUM;
  config.pin_xclk = XCLK_GPIO_NUM;
  config.pin_pclk = PCLK_GPIO_NUM;
  config.pin_vsync = VSYNC_GPIO_NUM;
  config.pin_href = HREF_GPIO_NUM;
  config.pin_sscb_sda = SIOD_GPIO_NUM;
  config.pin_sscb_scl = SIOC_GPIO_NUM;
  config.pin_pwdn = PWDN_GPIO_NUM;
  config.pin_reset = RESET_GPIO_NUM;
  config.xclk_freq_hz = 20000000;
  config.pixel_format = PIXFORMAT_JPEG; 
  
  if(psramFound()){
    config.frame_size = FRAMESIZE_UXGA; // FRAMESIZE_ + QVGA|CIF|VGA|SVGA|XGA|SXGA|UXGA
    config.jpeg_quality = 10;
    config.fb_count = 2;
  } else {
    config.frame_size = FRAMESIZE_SVGA;
    config.jpeg_quality = 12;
    config.fb_count = 1;
  }
  
  // Init Camera
  esp_err_t err = esp_camera_init(&config);
  if (err != ESP_OK) {
    Serial.printf("Camera init failed with error 0x%x", err);
    return;
  }

//https://randomnerdtutorials.com/esp32-cam-ov2640-camera-settings/

  sensor_t * s = esp_camera_sensor_get();
  s->set_brightness(s, 0);     // -2 to 2
  s->set_contrast(s, 0);       // -2 to 2
  s->set_saturation(s, 0);     // -2 to 2
  s->set_special_effect(s, 0); // 0 to 6 (0 - No Effect, 1 - Negative, 2 - Grayscale, 3 - Red Tint, 4 - Green Tint, 5 - Blue Tint, 6 - Sepia)
  s->set_whitebal(s, 1);       // 0 = disable , 1 = enable
  s->set_awb_gain(s, 1);       // 0 = disable , 1 = enable
  s->set_wb_mode(s, 0);        // 0 to 4 - if awb_gain enabled (0 - Auto, 1 - Sunny, 2 - Cloudy, 3 - Office, 4 - Home)
  s->set_exposure_ctrl(s, 1);  // 0 = disable , 1 = enable
  s->set_aec2(s, 0);           // 0 = disable , 1 = enable
  s->set_ae_level(s, 0);       // -2 to 2
  s->set_aec_value(s, 300);    // 0 to 1200
  s->set_gain_ctrl(s, 1);      // 0 = disable , 1 = enable
  s->set_agc_gain(s, 0);       // 0 to 30
  s->set_gainceiling(s, (gainceiling_t)0);  // 0 to 6
  s->set_bpc(s, 0);            // 0 = disable , 1 = enable
  s->set_wpc(s, 1);            // 0 = disable , 1 = enable
  s->set_raw_gma(s, 1);        // 0 = disable , 1 = enable
  s->set_lenc(s, 1);           // 0 = disable , 1 = enable
  s->set_hmirror(s, 0);        // 0 = disable , 1 = enable
  s->set_vflip(s, 0);          // 0 = disable , 1 = enable
  s->set_dcw(s, 1);            // 0 = disable , 1 = enable
  s->set_colorbar(s, 0);       // 0 = disable , 1 = enable




  
  //Serial.println("Starting SD Card");
  if(!SD_MMC.begin()){
    Serial.println("SD Card Mount Failed");
    return;
  }
  
  uint8_t cardType = SD_MMC.cardType();
  if(cardType == CARD_NONE){
    Serial.println("No SD Card attached");
    return;
  }
    
  camera_fb_t * fb = NULL;
  
  // Take Picture with Camera
  fb = esp_camera_fb_get();  
  if(!fb) {
    Serial.println("Camera capture failed");
    return;
  }
  // initialize EEPROM with predefined size
  EEPROM.begin(EEPROM_SIZE);
  pictureNumber = EEPROM.read(0) + 1;

  // Path where new picture will be saved in SD Card
  String path = "/picture" + String(pictureNumber) +".jpg";

  fs::FS &fs = SD_MMC; 
  Serial.printf("Picture file name: %s\n", path.c_str());
  
  File file = fs.open(path.c_str(), FILE_WRITE);
  if(!file){
    Serial.println("Failed to open file in writing mode");
  } 
  else {
    file.write(fb->buf, fb->len); // payload (image), payload length
    Serial.printf("Saved file to path: %s\n", path.c_str());
    EEPROM.write(0, pictureNumber);
    EEPROM.commit();
  }
  file.close();
  esp_camera_fb_return(fb); 
  
  // Turns off the ESP32-CAM white on-board LED (flash) connected to GPIO 4
  pinMode(4, OUTPUT);
  digitalWrite(4, LOW);
  rtc_gpio_hold_en(GPIO_NUM_4);
  
  delay(2000);
  Serial.println("Going to sleep now");
  delay(2000);
  esp_deep_sleep_start();
  Serial.println("This will never be printed");
}

void loop() {
  
}

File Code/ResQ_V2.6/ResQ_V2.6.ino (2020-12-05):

/*

Erics Open Source ResQ Search and Rescue Tool
My Youtube Channel  : http://www.youtube.com/mkmeorg
If you use this code or personalize it etc- please consider sharing it back with the world via the forum at http://www.mkme.org/forum
Website, Forum http://mkme.org
Chat with Me: Discord http://mkme.org/discord
Store http://mkme.org/store
  
This software is based on the work of Ray Burnette: https://www.hackster.io/rayburne/esp8266-mini-sniff-f6b93a
AND Human detector by Andreas Spiess
Handy info- VIDEO: https://www.youtube.com/watch?v=fmhjtzmLrg8 explains why apple devices not connected keep spamming new MAC's
Channel -2 in serial is what m iphone beacons on when not connected- Maybe minus channels are non connected?

This work is licensed under a Creative Commons Attribution-NonCommercial 4.0 International License.
https://creativecommons.org/licenses/by-nc/4.0/ 
IDE Used V1.8.8 - Use this or be forever in land of troubles....

V1 Spring 2020:
 V1.xxx standalone with oled and sd card working stable and usable
 Moving to Git HUUUUUUUUUUUUUUGE effaround as OLED and SPI wont work together- traced back to Adafruit libs and possibly RAM issue
 Switched to u8x8 lib WORKS!
 FINALLY displaying active APs and clients on OLED but this is VERY unstable.  2 uploads have caused gibberish serial output- slowed down to 57600 to test if related. 

 IDE Used: 1.8.8
 USE THIS PubClient lib- ONLY ONE THAT WORKS!!! https://github.com/heman4t/Arduino-pubsubclient
  
SD CARD STUFF
 * ERIC Confirms working using D5-D8 and no pullup 
 * 
 * This example shows how to log data from an analog sensor
 * to an SD card using the SD library.
 * The WeMos Micro SD Shield uses:
 * D5, D6, D7, D8, 3V3 and G
 * The shield uses SPI bus pins:
 * D5 = CLK
 * D6 = MISO
 * D7 = MOSI
 * D8 = CS

 
V2.1 July 2020
 GPS code incorporated and working
 High load soft resets if large # of beacons being indexed initially- seems fine after stabilising

2020-8-4
Note PCB V1.1 
 - OLED is VCC, GND then I2c- ALL my other OLEDs in the bin start with GROUND on the end.  blargh
 Of note- An oled can get hot enough to burn fingers...twice...and still work   ¯\_(ツ)_/¯
 Also check OLED VCC- looks like I may have used 5v instead of 3.3- no biggie but verify schematics someday eric....
 2020-8-4
 killed setp SD card fail return block- otherwise test stand rigs without SD will fail and hang and never sniff clients

V2.2 
 Put 10K pullup on MISO and it stopped the SD card shenanegins!
 Added SDOK status indicator and added to OLED display
Watchdog resets fought with delays and yield all over this code. Dont ask me to fix- not gonna touch them...>EVER
 Code is seemingly STABLE
 Still crashing whe long list of MACs is sent to serial - Moved hardware serial to 115200- YAY Fixed!
 9600 on hardare serial was causing the watchdog resets!!!!!!!!!!!!!!!!!!!!!!!!!
 derrrrp

 V2.3 Cleanup
 Remove logging APs to SD card as it just messus up the ability to import coordinates to Google maps easily

 V2.4 Camera trigger functions integration
 ESP32 Reset Pin is thrid down from ANt on left side. See pics in ref section
 D0 is triggered low every time a new MAC is written to the SD card
 D0 is tied directly to Reset Pin of ESP32 Camera module- this wakes it from deep sleep- takes a picture and goes back to sleep. EASY! 
 It worrrrrrrrrrrrrks!  Eric Tested 9-20-2020 and it works perfectly with just shared ground and signal D0 as signal/reset trigger. YAY DOne

V2.5 
2020-09-24
Sentry Mode Integration
It works!!!! 
Simply toggle the int in setup from SENTRYMODE=0 to 1 and 
The OLED will show init right up untill clients are detected to be written to SD card (you can use this to test function by NOT disabling wifi on your cell phone)
This allows you to see if SD card and GPS are both OK then OLED will turn off to save power.  AWESOME!
Method used is powersave mode right in the OLED library- so cool
Done deal- Setry mode now works and is fully supported to capture poachers, theives, whatever you like. Enjoy!

V2.6 
2020-09-24
Bluetooth integration!
Changed Baud rate of HC-05 Module as per this instruction https://shyyko.com/2015/07/13/changing_of_baud_rate_hc_05/
You need to program it one time with Serial adapter via AT commands:
"AT+UART=115200,1,0"
"AT+NAME=ResQ"
Works with android tabled at 115200 YAY!  Now we can monitor Resq from cockpit of light aircraft etc with air unit mounted outside the fuselage. 
 
*/


//Adding OLED Functions ERIC
#include <Arduino.h>
#include <U8x8lib.h>
#ifdef U8X8_HAVE_HW_SPI
#include <SPI.h>
#endif
U8X8_SSD1306_128X64_NONAME_SW_I2C u8x8(/* clock=*/ SCL, /* data=*/ SDA, /* reset=*/ U8X8_PIN_NONE);   // OLEDs without Reset of the Display
//End OLED add for this section ERIC

//GPS req's added
#include <SoftwareSerial.h>
#include <TinyGPS++.h>
TinyGPSPlus gps;  // The TinyGPS++ object
SoftwareSerial ss(2, 0);
float latitude , longitude;
int year , month , date, hour , minute , second;
String date_str , time_str , lat_str , lng_str;
int pm;
//End GPS

#include <SPI.h>
#include <SD.h>
// change this to match your SD shield or module;
// WeMos Micro SD Shield V1.0.0: D8
// LOLIN Micro SD Shield V1.2.0: D4 (Default)
const int chipSelect = D4;

//abandon all hope ye who try to clean the coming mess...
#include <ESP8266WiFi.h>
#include <ArduinoJson.h>
// #include <credentials.h>
#include <set>
#include <string>
#include "./functions.h"
#include "./mqtt.h"

#define disable 0
#define enable 1
#define SENDTIME 30000
#define MAXDEVICES 60
#define JBUFFER 15+ (MAXDEVICES * 40)
#define PURGETIME 60000 //was 600000  Shortened to test purge- WORKS!!!
#define MINRSSI -70

int SDOK = 1;//used to indicated if SD card is alive and still being written
int SENTRYMODE = 0; //Sentry Mode enable 1 disable 0 ------------------------------------------------------------------------------------- Sentry Mode Enable/Disable here 

// uint8_t channel = 1;
unsigned int channel = 1;
int clients_known_count_old, aps_known_count_old;
unsigned long sendEntry, deleteEntry;
char jsonString[JBUFFER];// working 

String device[MAXDEVICES];
int nbrDevices = 0;
int usedChannels[15];

#ifndef CREDENTIALS  //don't need this anymore- only for initial tests but I got the lazy so not gunna remove it
#define mySSID "*****"
#define myPASSWORD "******"
#endif
// JSON ALWAYS pissy about what version is installed- devs stop BREAKING CHANGES every month! Eric backed up the working lib in git for you... Install it or good luck adapting this mess
StaticJsonBuffer<JBUFFER>  jsonBuffer;

void setup() {
pinMode(D0, OUTPUT);     // Initialize the Camera Module Reset Pin

  
  //GPS Init
  ss.begin(9600); // software serial
  
  //OLED init
  u8x8.begin();
  u8x8.setPowerSave(0);
 //oled end init 
 Serial.begin(115200); //hardware serial - if you run at 9600 to match GPS WTD resets will happen and little children will go to bed hungry. Don't
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

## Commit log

2020-06-01 Add pcb from bak
    [ResQ PCB .fzz]
2020-06-03 box added
    [snap_box_both20200601-60-kt0mq8.stl, snap_box_box20200601-60-507ek2.stl, snap_box_top20200601-60-1631z0u.stl]
2020-07-11 Air Unit design
    [snap_box.scad, snap_box.stl, snap_box_both20200601-60-kt0mq8.stl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]
2020-07-11 Create Air Unit Case .PNG
2020-07-11 Interference Fit adjusted
    [snap_box.stl]
2020-07-12 Air unit
    [snap_box.stl]
2020-07-24 Update ResQ_V2.1_OLED_SD_GPS.ino
    Fixed duplicate calls to GPS Software serial
    [ResQ_V2.1_OLED_SD_GPS.ino]
2020-07-24 Update ResQ_V2.1_OLED_SD_GPS.ino
    Fixed SD delimitiers for logging. Still crashes periodically
    [ResQ_V2.1_OLED_SD_GPS.ino]
2020-07-24 Update ResQ PCB .fzz
    [ResQ PCB .fzz]
2020-07-26 Create ResQ PCB V1.1 Routing .fzz
    [ResQ PCB V1.1 Routing .fzz]
2020-07-26 Update ResQ PCB V1.1 Routing .fzz
    [ResQ PCB V1.1 Routing .fzz]
2020-07-26 Boar v1.1 complete
    [ResQ PCB .fzz, ResQ PCB V1.1 Routing .fzz, ResQ PCB V1.1 Routing PCB 2 .fzz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]
2020-07-27 Create How to Manually Panelize PCBs - YouTube.url
2020-08-02 Aircraft Files Added
    Mergging from Drone Configs for anyone wishing to directly duplicate all inav settings and build
    [F722_wing_fc_holder.stl, Hatch1.stl, Hatch2.stl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]
2020-08-04 Camera Expansion Module
2020-08-04 Cam Module Updates
    [BOM.ods, BOM.xlsx]
2020-08-05 V3 coming
    [snap_box.scad]
2020-08-05 Reorg and Air Unit CAD Files
    [Air Unit Enclosure v9.f3d, Body1.stl, Case.stl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]
2020-08-05 New Air Unit Enclosure
    [Case.stl, Top Cover.stl]
2020-08-06 New Air Unit box
    [Air Unit Enclosure v16.f3d, Case.stl, Top Cover new.stl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]
2020-08-08 PCB Pics archive
2020-08-10 KiCad New PCB and Schematic Files
    [ResQ KiCad Version.kicad_pcb, ResQ KiCad Version.sch]
2020-08-10 KiCad Updates
    [ResQ KiCad Version.sch]
2020-08-10 Updated Kicad Schem
    [ResQ KiCad Version.sch]
2020-08-10 KiCAD Schematics Completed
    [ResQ KiCad Version.sch]
2020-08-11 KiCAD Project Updates
    [ResQ KiCad Version.kicad_pcb, ResQ KiCad Version.sch]
2020-08-12 Create KiCad before Routing .PNG
2020-08-12 oled pinout reversal
    [ResQ KiCad Version.kicad_pcb, ResQ KiCad Version.sch]
2020-08-13 BOM Updates
    [BOM.xlsx]
2020-08-13 folder structure for enclosures fixed
    [Air Unit Enclosure v18.f3d, Air Unit Enclosure v9.f3d, Body1.stl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]
2020-08-16 Purdier schematic
    [ResQ KiCad Version.sch]
2020-08-16 Purdy schematico
    [ResQ KiCad Version.sch]
2020-08-16 Schematic purrdy
    [ResQ KiCad Version.sch]
2020-08-17 Schematic Updates
    [ResQ KiCad Version.sch]
2020-08-17 Telemetry radio added
    [ResQ KiCad Version.sch]
2020-08-18 Scematic fixes
    [ResQ KiCad Version.kicad_pcb, ResQ KiCad Version.sch]
2020-08-18 PCB pics added
2020-08-22 Camera Module added
    [ResQ KiCad Version.kicad_pcb, ResQ KiCad Version.sch, ResQ PCB .fzz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]
2020-08-23 Narrowed OLED Cutout
    [Ground Unit Enclosure v4.f3d, V1.3 Enclosure.stl, V1.3 Top Cover.stl]
2020-08-24 Re-org for new modules and docs
    [ESP32_CAM_v10.step, all_in_one_print.stl, body.stl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]
2020-08-24 Create Schematic V2.1 fixed Color.PNG
2020-08-24 Schematic fixes
2020-08-26 BOM & Pics Updates
    [BOM.xlsx]
2020-08-28 Laser Cut version
    Yay now anyone can make this without a 3D printer
    [box.dxf]
2020-08-28 NEW Laser Cut Cases YAY
    [Air Unit Enclosure v18.f3d, Air Unit Enclosure v9.f3d, Body1.stl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]
2020-08-28 Re-org for laser cut version
    [Air Unit Enclosure v18.f3d, Air Unit Enclosure v9.f3d, Body1.stl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]
2020-08-28 Rename Flow Diagrams to Useful Names
2020-08-29 New laser cut svg
    [box.dxf]
2020-08-29 New enclosure
2020-08-29 Update box for laser- text mirrored.svg
2020-08-29 Create box for laser- text mirrored new fnt.svg
2020-08-29 V1.4 Is perfect I'm DONE!
    [box.dxf]
2020-08-29 2D SVG files for Air Unit Enclosure Added
    [box.dxf]
2020-08-29 Create case svg .PNG
2020-08-30 Ground Enclosure Design Done
    [box.dxf]
2020-08-30 Ground enclosure svg
2020-08-30 Ground enclosure SVG Complete
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2020-09-06 Beginning PCB V2.Xxx Design
    [ResQ KiCad Version.kicad_pcb, ResQ KiCad Version.sch]
2020-09-06 PCB Version 2.1 routed
    [ResQ KiCad Version.kicad_pcb, ResQ KiCad Version.sch]
2020-09-06 PCB Updates
    [ResQ KiCad Version-B_Cu.gbl, ResQ KiCad Version-B_Mask.gbs, ResQ KiCad Version-B_Paste.gbp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]
2020-09-06 Create ResQ KiCad Version-B_Cu.zip
2020-09-06 PCB V2.1 Complete
    [ResQ PCB .fzz, ResQ PCB V1.1 Routing .fzz]
2020-09-06 Create V2.1 schematic as ordered .PNG
2020-09-06 Gerber pictures as ordered
2020-09-06 Create PCB Final in KiCad.PNG
2020-09-07 PCB and schematic readme added
2020-09-08 Added Dimensions Only
    [ResQ KiCad Version.kicad_pcb]
2020-09-08 PCB V2.2 Template created
    [ResQ KiCad Version.kicad_pcb, ResQ KiCad Version.sch]
2020-09-13 Updates
    Code,Cam and sentry modes
    [Case.stl, ESP32_CAM_v10.step, Top Cover.stl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]
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2020-09-19 .step source files added
    [Air Enclosure.step, Camera Enclosure.step, Ground Enclosure.step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]
2020-09-20 Cam updates
    [Camera Enclosure.step, Case.stl, Top Cover.stl]
2020-09-20 Cam Enclosures
    [Camera Enclosure.step, Case.stl, SentryEnclosure.step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]
2020-09-20 ResQ Camera Integration COMPLETE!!!!
2020-09-21 Camera Module Integration COMPLETE!
    It works!
    [Camera Enclosure.step, Case.stl, SentryEnclosure.step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]
2020-09-21 Update Flow Diagram .drawio
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2020-09-23 ResQ Camera Updates
    Reverted whitebalance settings to Auto in main code
    [ResQ_Camera_Module_V1.2.ino]
2020-09-24 Kanban Board Current Status
2020-09-24 ResQ Sentry
    [Case.stl, ResQ Sentry v10.step, SentryEnclosure.step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]
2020-09-24 Sentry Mode Integration Done!
    Enable Sentry mode parameter in code and OLED will turn off after init to save power. Nice
2020-09-25 Bluetooth Integration Complete!
    We can now talk to HC05 bluetooth module at 115200 baud no problem! Yay
    [ResQ_V2.6.ino]
2020-10-04 User and Assembly Manual + System Design Doc
2020-10-14 New PCBs and Kits
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
